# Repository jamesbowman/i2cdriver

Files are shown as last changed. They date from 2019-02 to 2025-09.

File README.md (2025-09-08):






I2CDriver is a tool for controlling any I2C device from your PC's USB port,
and can also monitor and capture I2C traffic.
It connects as a standard USB serial device, so there are no drivers to install.
On the main site
[i2cdriver.com](https://i2cdriver.com),
there are drivers for

* Windows/Mac/Linux GUI
* Windows/Mac/Linux command-line
* Python 2 and 3
* Windows/Mac/Linux C/C++

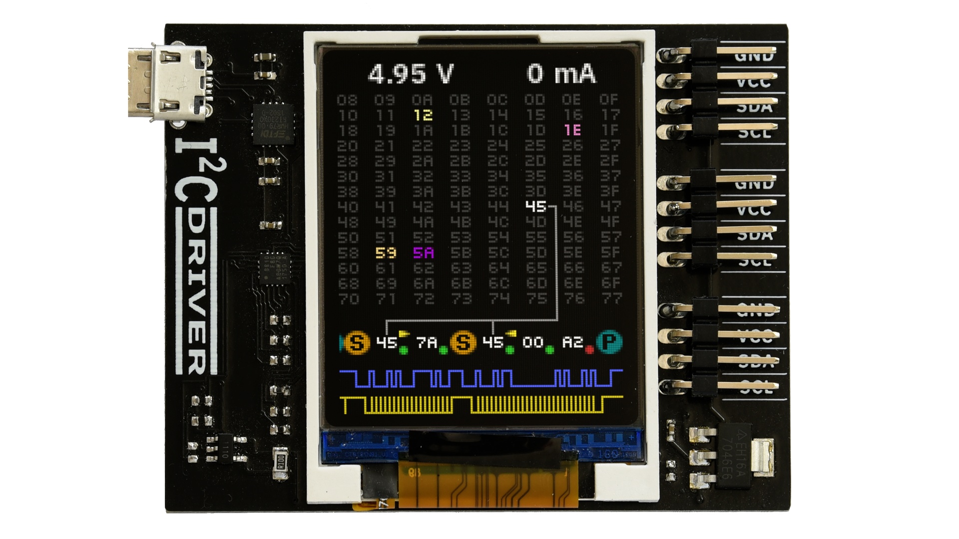
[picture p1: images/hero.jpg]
front


Full documentation is at
[i2cdriver.com](http://i2cdriver.com).

For developers: How to make a release
-------------------------------------

To release Python:

    cd python3
    rm -rf dist/*
    python -m build
    twine check dist/*
    twine upload dist/*

To build the Windows installer, you first need to build the two executables
``i2ccl.exe`` and ``i2cgui.exe`` then use an NSIS script to create the installer.

On Linux cross-compile ``i2ccl``:
  
    cd c
    make -f win32/Makefile

On Windows first make sure that you can run the GUI on the command-line, e.g.

    python python\samples\i2cgui.py

(You may need to install i2cdriver, wxPython and pySerial).

Then build the GUI executable using ``pyinstaller``:

    cd python\samples
    pyinstaller --onefile --windowed --icon=../../images/i2cdriver.ico i2cgui.py

This builds the executable in ``python\samples\dist\i2cgui.exe``.

The Windows installer is built with NSIS (Nullsoft Scriptable Install System). Download and install it.

Copy the two executables ``i2ccl.exe`` and ``i2cgui.exe`` into ``nsis/``.

Then build the installer with NSIS:

    cd nsis
    "C:\Program Files\NSIS\makensis.exe" i2cdriver.nsi

The script ``go.bat`` in ``nsis`` has an example complete flow.

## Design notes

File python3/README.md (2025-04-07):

i2cdriver
=========

I2CDriver is a tool for controlling, monitoring and capturing I2C from your PC's USB port. It connects as a standard USB serial device, so there are no drivers to install."""

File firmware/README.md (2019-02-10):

This is the firmware for the I2CDriver.
It uses the [MyForth](http://www.kiblerelectronics.com/myf/myf.shtml) compiler written by
Charley Shattuck and Bob Nash.

To compile the fonts go into ``assets``
and run ``mkfont.py``. This builds the font sources in ``fonts.fs``

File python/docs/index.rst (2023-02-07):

i2cdriver
=========

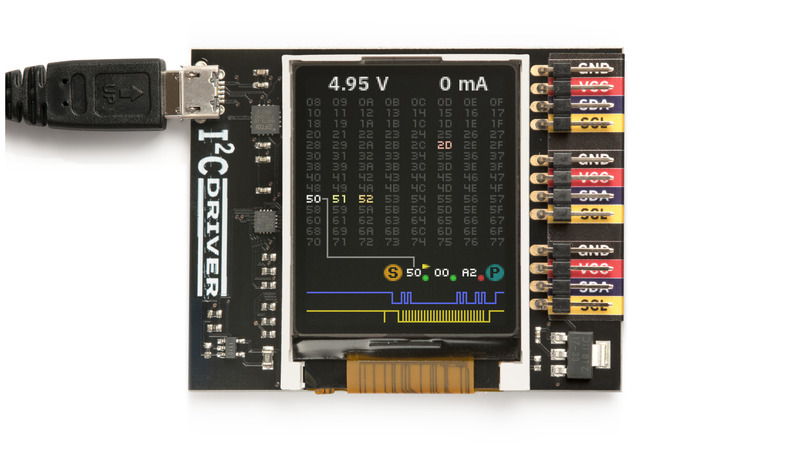
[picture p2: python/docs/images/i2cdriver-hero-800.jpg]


`I²CDriver <https://i2cdriver.com>`_
is an easy-to-use, open source tool for controlling I²C devices over USB.
It works with Windows, Mac, and Linux, and has a built-in color screen
that shows a live "dashboard" of all the I²C activity.

.. toctree::
   :maxdepth: 2
   :caption: Contents:

The I²CDriver User Guide has complete information on the hardware:

https://i2cdriver.com/i2cdriver.pdf

System Requirements
===================

Because it is a pure Python module, ``i2cdriver`` can run on any system supported by ``pyserial``.
This includes:

- Windows 7 or 10
- Mac OS
- Linux, including all Ubuntu distributions

Both Python 2.7 and 3.x are supported.

Installation
------------

The ``i2cdriver`` package can be installed from PyPI using ``pip``::

    $ pip install i2cdriver

Quick start
-----------

To connect to the I2CDriver and scan the bus for connected devices::

    >>> import i2cdriver
    >>> i2c = i2cdriver.I2CDriver("/dev/ttyUSB0")
    >>> i2c.scan()
    -- -- -- -- -- -- -- -- 
    -- -- -- -- -- -- -- -- 
    -- -- -- -- 1C -- -- -- 
    -- -- -- -- -- -- -- -- 
    -- -- -- -- -- -- -- -- 
    -- -- -- -- -- -- -- -- 
    -- -- -- -- -- -- -- -- 
    -- -- -- -- -- -- -- -- 
    48 -- -- -- -- -- -- -- 
    -- -- -- -- -- -- -- -- 
    -- -- -- -- -- -- -- -- 
    -- -- -- -- -- -- -- -- 
    68 -- -- -- -- -- -- -- 
    -- -- -- -- -- -- -- -- 
    [28, 72, 104]

To read the temperature in Celsius from a connected LM75 sensor:

    >>> d=i2cdriver.EDS.Temp(i2c)
    >>> d.read()
    17.875
    >>> d.read()
    18.0

The User Guide at https://i2cdriver.com has more examples.

Module Contents
---------------

.. autoclass:: i2cdriver.I2CDriver
   :member-order: bysource
   :members:
      setspeed,
      setpullups,
      scan,
      reset,
      start,
      read,
      write,
      stop,
      regwr,
      regrd,
      getstatus,
      monitor

.. autoclass:: i2cdriver.START
.. autoclass:: i2cdriver.STOP
.. autoclass:: i2cdriver.BYTE

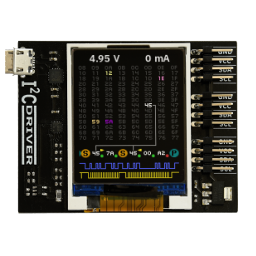
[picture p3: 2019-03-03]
images/i2cdriver.png

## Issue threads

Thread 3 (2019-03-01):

Seems to hang ?

lakidd, 2019-03-01:
Hi I've just received my i2cdriver.
I plug it in and it lights up with the default screen, but it doesn't 'do' anything. When running i2ccl with the correct device name, it just seems to hang, i don't get the status line like your example.
Any hints on troubleshooting ?
Sorry this is on OSX. The python gui also seems to have issues with
```
TypeError: GridSizer(): arguments did not match any overloaded call:
  overload 1: not enough arguments
  overload 2: argument 2 has unexpected type 'int'
  overload 3: not enough arguments
  overload 4: not enough arguments

```
And from my reading, it does need 3x parameters in the call.
Thanks

jamesbowman, 2019-03-01:
What device name are you using? Something like:

``/dev/cu.usbserial-XXXXXXXX``

?

lakidd, 2019-03-01:
Aha its /dev/tty.usbserial-WEATHER...when i change to the cu.usbserial-WEATHER, it comes good, thanks.
What is the difference between those nodes ? I've never understood why both appear and for all other arduino, esp stuff the tty nodes work fine.
Any thoughts on the python issue ?

jamesbowman, 2019-03-01:
Yes it is subtle, but this explains tty vs cu in more detail.

https://pbxbook.com/other/mac-tty.html

Please can you raise a new issue for the Python GUI? (WX changed the parameters of GridSizer between versions.)

jamesbowman, 2019-03-02:
OK, think this is closed.

Closed 2019-03-02.

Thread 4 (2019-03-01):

Python GUI crashes

lakidd, 2019-03-01:
When running the python gui I get

`Traceback (most recent call last):
  File "./i2cgui.py", line 215, in <module>
    f = Frame()
  File "./i2cgui.py", line 99, in __init__
    devgrid = wx.GridSizer(14, 8)
TypeError: GridSizer(): arguments did not match any overloaded call:
  overload 1: not enough arguments
  overload 2: argument 2 has unexpected type 'int'
  overload 3: not enough arguments
  overload 4: not enough arguments`

Has GridSizer in wxPython changed ?

jamesbowman, 2019-03-02:
Confirmed fixed on wx. Closing.

Closed 2019-03-02.

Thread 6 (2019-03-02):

i2cgui is not functional code.

rhyde, 2019-03-02:
I have fixed a couple obvious problems but I quickly realized that this is at best a stub and very little works.  When will a tool that was advertised be available?
Issues: Wrong number of arguments creating the grid layout.
Can't handle non i2c usb-serial devices.

Randomly will not connect claiming bus is busy

jamesbowman, 2019-03-02:
Good points... this in progress.

When it says the bus is busy, what does the ``i2ccl <port> i`` report?

rhyde, 2019-03-02:
The client tool is responding as expected.

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

jamesbowman, 2019-03-02:
Hmm, and ``i2ccl <port> d`` produces a reasonable port scan?

jamesbowman, 2019-03-04:
Think it is feature complete now. Tested on Mac, seems to be usable.
Raised #7 to cover the work to expose the programmable pull-ups.

jamesbowman, 2019-03-04:
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

Closed 2019-03-08.

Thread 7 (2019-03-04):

Feature: Programmable pull-ups

jamesbowman, 2019-03-04:
Need to:
- [ ] document the bit-field
- [ ] expose a proper API
- [ ] add to GUI
- [ ] make a new release

lucasdemarchi, 2019-04-03:
where's the programmable pullup documented? Currently if I read it from python it returns 36. Only place I found a comment was in the code, saying

```
  unsigned int pullups;   // pullup state (6 bits, 1=enabled)
```

Do we have 1 pullup for each SDA/SCL pin? So... are those separate I2C busses? I thought it was a shared bus.

jamesbowman, 2019-04-03:
I've written up how they work here:

https://i2cdriver.com/#pull-up-resistors

next step is to add a control to the GUI.

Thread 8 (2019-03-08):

Where is protocol.md?

njh, 2019-03-08:
Hi,

Just read about this project on an email from Cool Components - looks great!

I just clicked on 'The serial protocol is **very simple**, and there are included drivers for' and got a 404. Where can I find out about the protocol?

Thanks,

nick.

jamesbowman, 2019-03-08:
Fixed the old text, copy-pasted from SPIDriver.
The protocol is covered here

https://i2cdriver.com/#raw-protocol

njh, 2019-03-08:
Ah, great, thanks.

It might be good to add a link to https://i2cdriver.com/ in the header of the Github repo.

jamesbowman, 2019-03-08:
Good idea - done.

Closed 2019-03-08.

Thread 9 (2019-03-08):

I2CDriver Windows release build not working

rlramirez77, 2019-03-08:
1. Need to add a note for users to edit the go.bat with their destination path for i2cdriver-installer.exe output, or have the path resolve for the user automatically
2. Need to mention that Nullsoft Scripting, NSIS is a dependency, user to download and install it
3. Need to reconcile line #63 in i2cdriver.nsi - file "i2ccl.exe" - commenting the line out allows i2cdriver-installer to build, but execution of I2CDriver GUI fails with "Failed to execute script"

jamesbowman, 2019-03-10:
@rlramirez77 when it says "Failed to execute script" what other error text is shown.

rlramirez77, 2019-03-10:
> @rlramirez77 when it says "Failed to execute script" what other error text is shown.

No other message/text, the error is presented in a modal dialog - so it's a typical helpful Windows error message - kek

jamesbowman, 2019-03-10:
OK, to see more error information, do:

    pyinstaller --onefile --icon=../../images/i2cdriver.ico i2cgui.py

(i.e. no ``--windowed`` option). This will leave the console window open and print any error message when the ``.exe`` runs.

rlramirez77, 2019-03-10:
Corresponding output from suggested run (Anaconda is up to date):

(base) C:\Users\Administrator\Downloads\i2cdriver-master\i2cdriver-master\python\samples>pyinstaller --onefile --icon=../../images/i2cdriver.ico i2cgui.py
46 INFO: PyInstaller: 3.4
46 INFO: Python: 3.7.1
46 INFO: Platform: Windows-10-10.0.14393-SP0
46 INFO: wrote C:\Users\Administrator\Downloads\i2cdriver-master\i2cdriver-master\python\samples\i2cgui.spec
46 INFO: UPX is not available.
46 INFO: Extending PYTHONPATH with paths
['C:\\Users\\Administrator\\Downloads\\i2cdriver-master\\i2cdriver-master\\python\\samples',
 'C:\\Users\\Administrator\\Downloads\\i2cdriver-master\\i2cdriver-master\\python\\samples']
62 INFO: checking Analysis
93 INFO: checking PYZ
109 INFO: checking PKG
125 INFO: Bootloader c:\programdata\anaconda3\lib\site-packages\PyInstaller\bootloader\Windows-64bit\run.exe
125 INFO: checking EXE
140 INFO: Building because console changed
140 INFO: Building EXE from EXE-00.toc
249 INFO: SRCPATH [('..\\..\\images\\i2cdriver.ico', None)]
249 INFO: Updating icons from ['..\\..\\images\\i2cdriver.ico'] to C:\Users\ADMINI~1\AppData\Local\Temp\1\tmphuc9ffz2
265 INFO: Writing RT_GROUP_ICON 0 resource with 20 bytes
265 INFO: Writing RT_ICON 1 resource with 75484 bytes
328 INFO: Appending archive to EXE C:\Users\Administrator\Downloads\i2cdriver-master\i2cdriver-master\python\samples\dist\i2cgui.exe
437 INFO: Building EXE from EXE-00.toc completed successfully.

jamesbowman, 2019-03-10:
Looks good... and what does it say when you run ``dist\i2cgui.exe``?

rlramirez77, 2019-03-10:
How do I resolve this dependency?

Traceback (most recent call last):
  File "i2cgui.py", line 11, in <module>
ModuleNotFoundError: No module named 'wx'
[3264] Failed to execute script i2cgui

jamesbowman, 2019-03-10:
It needs wxPython, installation instructions are here

https://www.wxpython.org/pages/downloads/

if you are on Anaconda then it is here:

https://anaconda.org/anaconda/wxpython

rlramirez77, 2019-03-10:
Installed via Anaconda - same line 11 error.

jamesbowman, 2019-03-10:
OK, if you run it from the command-line with:

    python i2cgui.py

then do you see the same message about ``No module named 'wx'``?

rlramirez77, 2019-03-10:
Getting closer to the error:

(base) C:\Users\Administrator\Downloads\i2cdriver-master\i2cdriver-master\python\samples>python i2cgui.py
Traceback (most recent call last):
  File "i2cgui.py", line 14, in <module>
    from i2cdriver import I2CDriver
  File "C:\ProgramData\Anaconda3\lib\site-packages\i2cdriver.py", line 13, in <module>
    import bargraph
  File "C:\Users\Administrator\Downloads\i2cdriver-master\i2cdriver-master\python\samples\bargraph.py", line 10, in <module>
    from i2cdriver import I2CDriver
ImportError: cannot import name 'I2CDriver' from 'i2cdriver' (C:\ProgramData\Anaconda3\lib\site-packages\i2cdriver.py)

jamesbowman, 2019-03-10:
Aha. please update i2cdriver:

    pip install -U i2cdriver

rlramirez77, 2019-03-10:
Better, but 2 things. How do I specify COM9 as an argument to the executable? Like SPIDriver does, I would not throw an error if the i2cdriver hardware is unplugged when the GUI is run.

(base) C:\Users\Administrator\Downloads\i2cdriver-master\i2cdriver-master\python\samples\dist>i2cgui.exe
Traceback (most recent call last):
  File "i2cgui.py", line 334, in <module>
  File "i2cgui.py", line 209, in __init__
  File "i2cgui.py", line 266, in connect
  File "site-packages\i2cdriver.py", line 47, in __init__
  File "site-packages\serial\serialwin32.py", line 31, in __init__
  File "site-packages\serial\serialutil.py", line 240, in __init__
  File "site-packages\serial\serialwin32.py", line 62, in open
serial.serialutil.SerialException: could not open port 'COM1': PermissionError(13, 'Access is denied.', None, 5)
[7200] Failed to execute script i2cgui

bruceephx, 2019-03-17:
I just received my I2CDriver kit and following the getting-started page I downloaded the Windows Installer program and ran it as Administrator.  It seemed to install the i2cgui.exe and the i2ccl.exe without issue.  I ran the i2cgui.exe as Adminsitrator and I keep getting the "Failed to execute script i2cgui" response.  I'm running Windows 10 Pro x64 latest release.

I just tried the command line "i2ccl.exe" COM2 i" and that gave the response from the I2CDriver board with stats.  So the board appears to be running and communicating.

Ideas or thoughts?

jamesbowman, 2019-03-17:
Hi @bruceephx - What is the output of the "mode" command? Are there other COM ports? That might be a clue as to why i2cgui is failing.

jamesbowman, 2019-03-18:
@rlramirez77 and @bruceephx  I have built the new version of i2cgui at:

https://excamera.com/files/i2cgui.exe

This version is a bit more robust about handling ports, accepts a port on the command-line, and displays a dialog if it catches a fault. Please let me know how it works. Thanks.

rlramirez77, 2019-03-24:
That has it working now, thanks.

jamesbowman, 2019-03-26:
Great, thanks. Closing.

Closed 2019-03-26.

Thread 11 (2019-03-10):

Unable to see Stop button in 1366 x 768 screen resolution

gojimmypi, 2019-03-10:
perhaps the radio buttons can be vertically pushed closer together a bit, or add a scrollbar for those that have lower resolution screens? I would have submitted PR for this, but could not find the GUI version source code.

jamesbowman, 2019-03-10:
Aha, this is on Windows.
Sure, there are a couple of changes I can make.
btw the source is at ``python/samples/i2cgui.py``

jamesbowman, 2019-03-10:
Yes, pushing the radio buttons closer together looks good. Now fits in 768:

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

gojimmypi, 2019-03-10:
yes, that works perfectly! (and looks better, too -  in addition to being able to see the Stop button)

thank you for the prompt response & I didn't realize Windows GUI was python based.

Closed 2019-03-10.

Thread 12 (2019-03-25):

Windows app buttons disabled at startup

gojimmypi, 2019-03-25:
I'm test driving an INA219 I2C current sensor. The I2CDriver board sees the device at address x40, but the `read` and `write` buttons are initially disabled.

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

If I plug in a second device, Ic2 address = x60, select that one and then go back and select the 0x40 device, the buttons are then enabled.

jamesbowman, 2019-03-26:
This seems to be a difference in radio button behavior between our versions of Windows. Surprising!

If you start with 0x40 attached, then click on the 0x40 radio button, do "read" and "write" light up?

When I start it with a single device (74 in my case) the device map doesn't light up, I have to click it. Then the RADIOBUTTON event happens and the GUI enables the buttons:

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

I'm running Windows 10.

gojimmypi, 2019-03-28:
Well, I found a sequence of events to reproduce this. The last time it seemed that the problem continually occurred.

With the I2CDriver powered off, plug in a device. (I plugged mine into the connector closest to the top of the display).  Launch the software. No items are selected and the buttons are grayed out. Click the ID of your selected item (in my case 40). The `Read` and `Write` buttons become active.

While leaving the I2CDriver board powered up, unplug the single I2C test device. The `Read` and `Write` buttons become inactive and grayed out. The selected device radio button remains selected, but also grayed out.

Re-plug the I2C device. The software recognizes that a device has been plugged in, the radio button selection is no longer grayed out - however clicking on it does not enable the buttons, perhaps because the radio button was already selected? Having only one device - there's no way to un-select and re-select it.

It seems that perhaps the  `Read` and `Write`  buttons are enabled only upon a state change from the radio button not selected to selected.

I'm also running Windows:
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

jamesbowman, 2019-03-29:
Aha, that's very clear, thanks.

I committed a fix, and built a test binary here:

https://excamera.com/files/i2cgui.exe

jamesbowman, 2020-01-08:
Fixed, closing.

Closed 2020-01-08.

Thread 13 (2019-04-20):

Capture Mode

brotherdust, 2019-04-20:
Hi!
THANK YOU for making this device! It's so useful!

While looking through the [documentation](https://i2cdriver.com/), I noticed there's a stub header for "Capture Mode", but nothing below it. Are there any plans for a capture mode to be supported? If so, when? I'd like to contribute to your project where I can, so I'd be happy to write up the documentation for this feature once it's available.

Thanks!

simon-rob, 2019-04-29:
+1
I twas hoping capture mode would allow capturing of I2C frames as monitor mode seems only to so the current frame on the display which is limited in use when debugging. (due to the small screen)

jamesbowman, 2019-04-29:
Hi all, yes, really sorry this isn't. It's coming today.

simon-rob, 2019-04-29:
Great, looking forward to giving it ago.

jamesbowman, 2019-04-30:
Capture to file is implemented in the new release 0.0.5.

https://i2cdriver.com/windows

It's documented on p.18 of the user guide:

https://i2cdriver.com/i2cdriver.pdf

Note that there's no live graphical display at the yet, but the command-line version does print all the traffic as it arrives.

simon-rob, 2019-04-30:
James,

I am using Python 2.7  and I get the follow error when trying to capture:
  File "/usr/lib/python2.7/threading.py", line 801, in __bootstrap_inner
    self.run()
  File "/usr/lib/python2.7/threading.py", line 754, in run
    self.__target(*self.__args, **self.__kwargs)
  File "i2cgui.py", line 48, in capture_thr
    c = sd.capture_start(True)
TypeError: capture_start() takes exactly 1 argument (2 given)

If I remove from capture_start() I then get:
  File "/usr/lib/python2.7/threading.py", line 801, in __bootstrap_inner
    self.run()
  File "/usr/lib/python2.7/threading.py", line 754, in run
    self.__target(*self.__args, **self.__kwargs)
  File "i2cgui.py", line 52, in capture_thr
    for token in c():
  File "build/bdist.linux-x86_64/egg/i2cdriver.py", line 261, in parser
    for n in nstream():
  File "build/bdist.linux-x86_64/egg/i2cdriver.py", line 258, in nstream
    yield (b >> 4) & 0xf
TypeError: unsupported operand type(s) for >>: 'str' and 'int'

I see that i2cdriver.py has support for PYTHON2, but i guess some of the new capture code needs adapting! (I did have a go, but it kept giving the same error on 258 to my surprise)

Simon

jamesbowman, 2019-05-02:
@simon-rob I think you might be running the latest gui with an old i2cdriver. Did you do

  pip install -U i2cdriver

(or similar) before running the GUI?

simon-rob, 2019-05-02:
James,

I have run python2 setup.py install
I also tried pip install -U i2driver

but I still get:

  File "/usr/lib/python2.7/threading.py", line 801, in __bootstrap_inner
    self.run()
  File "/usr/lib/python2.7/threading.py", line 754, in run
    self.__target(*self.__args, **self.__kwargs)
  File "i2cgui.py", line 47, in capture_thr
    c = sd.capture_start(True)
TypeError: capture_start() takes exactly 1 argument (2 given)

jamesbowman, 2019-05-02:
That definitely looks like a version mismatch because capture_start's signature changed in 0.0.5.

If I do:

```
$ python2
Python 2.7.6 (default, Oct 26 2016, 20:30:19)
[GCC 4.8.4] on linux2
Type "help", "copyright", "credits" or "license" for more information.
>>> import i2cdriver
>>> i2cdriver.__version__
'0.0.5'
```

do you get the same version 0.0.5?

simon-rob, 2019-05-02:
James,

No, I get version 0.0.4.

I have uninstalled the i2cdriver using  pip uninstall i2driver and then reinstalled it again..

Now no error and the correct version 0.0.5.

Thanks for you help,

Simon

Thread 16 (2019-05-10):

I2CDRIVER.C won't compile with MSVC

TheSlat, 2019-05-10:
The following code fails to compile in Visual Studio 2019 with the error:
```
Severity	Code	Description	File	Line	Suppression State
Error	C2133	'mm': unknown size	..\i2cdriver.c	42
Error	C2057	expected constant expression	..\i2cdriver.c	42
Error	C2466	cannot allocate an array of constant size 0	..\i2cdriver.c	42

```

https://github.com/jamesbowman/i2cdriver/blob/2697bf5046094cddbebcbdee89a480c77b5c3f22/c/common/i2cdriver.c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

my quick fix:
```
    char mm[256];
    sprintf(mm, "%s failed with error %lu:\n%s", func_name, dw, (char*)lpMsgBuf);
```
unsure if there is a better way, just wanted to open the issue.

Also, I would suggest placing `#define NOMINMAX` before including windows.h to prevent windows from defining the min and max macros and clashing with other code.

TheSlat, 2019-05-11:
Also noticed that I had moved `#include <unistd.h>` to the `#if !defined(WIN32)` section since MSVC doesn't have that header and mingw doesn't need it. Also a `==` where i think there should be a `=` on line 58.

If you want I can fork and open a pull request to group these things together, I am using both the I2C driver and SPI driver pretty heavily in MSVC at work.

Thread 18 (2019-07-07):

Can't connect in Linux/Ubuntu

kylemallory, 2019-07-07:
I recently purchased this, and was really excited about using it for some of my embedded development. It took a bit to get wxPython installed property on Ubuntu (needed a bunch of additional packages that were in your instructions), but eventually I got it sorted.

Now that it's installed, I can run i2cgui.py, but I can't select a serial port from the drop down. I can see the /dev/ttyUSB0 being created when I connect it, and my user has 'dialout' permissions, but the GUI is almost entirely grayed out, and there is no output on the console.

I'd love to see this work. Any ideas for what might be causing the problems, or steps for further troubleshooting?

Thanks!

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

jamesbowman, 2019-07-07:
First question, when you attach the I2CDriver, does the I2CDriver's screen light up, and does it appear as a new device, like ``/dev/ttyUSB0``?

kylemallory, 2019-07-07:
Yes, it powers on, the display shows, and the OS detects the USB device, and registers as /dev/ttyUSB0. I have added my user to the "dialout" group, so permissions appear not to be a problem either.  Is there a 'debug' or 'logging' argument for the i2cgui.py that I can try?

jamesbowman, 2019-07-07:
OK, that narrows it down.

- [ ] Can I confirm that you logged out and back in, so the dialout group change took effect?
- [ ] The command-line tool might show the problem, if you build it and do ``i2ccl /dev/ttyUSB0 i`` what does it show?

kylemallory, 2019-07-07:
I also just noticed; when I start `i2cgui.py` the LCD backlight will brighten for about 2 seconds, and then dim back to normal.  If I close the app, and reopen, the same "bright/dim" change repeats each time I restart it.

kylemallory, 2019-07-07:
I can completely rebooted after adding myself to the group.  I'll try the `i2ccl` tool...

kylemallory, 2019-07-07:
Cloned, built, and ran...
```
$ ./i2ccl /dev/ttyUSB0 i
uptime 19945  5.388 V  0 mA  23.0 C SDA=0 SCL=1 speed=100 kHz
```
However:
```
$ ./i2ccl /dev/ttyUSB0 d
```
seems to hang indefinitely (I can abort/Ctrl+C).  Calling `i2ccl /dev/ttyUSB0 i` a second time also hung.  I had a i2c LCD display connected.  I remove that, and powered off the i2cdriver, and repowered.  At this point, both queries returned successfully.

I tried a different OLED display, and the device is working correctly, including in i2cgui.py.

There must have been something about the other LCD display that was messing up i2cdriver.  I think we can close this ticket, unless you'd like to do any additional troubleshooting to try and figure out what it going on.

Closed 2020-01-08.

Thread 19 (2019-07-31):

Issue with GUI on MacOS 10.14.6

joshrawls, 2019-07-31:
I have the device working, occasionally. When it doesn't work I get a few errors in terminal.

I'm still learning programming in general and new to Python, so any help would be appreciated. Thanks!

The first error only appears once:

`Traceback (most recent call last):
  File "/usr/local/bin/i2cgui.py", line 342, in refresh
    devs = self.sd.scan(True)
  File "/Library/Python/2.7/site-packages/i2cdriver.py", line 180, in scan
    d = struct.unpack("112c", self.ser.read(112))
struct.error: unpack requires a string argument of length 112
`

The second error loops until I terminate it:
`Traceback (most recent call last):
  File "/usr/local/bin/i2cgui.py", line 323, in refresh
    self.sd.getstatus()
  File "/Library/Python/2.7/site-packages/i2cdriver.py", line 449, in getstatus
    ccitt_crc) = body.split()
ValueError: need more than 0 values to unpack`

g5pw, 2021-04-10:
Uh, I'm seeing the same error on macOS Big Sur 11.2.3. Did you manage to solve it in any way?

jamesbowman, 2021-04-10:
@g5pw does this error happen intermittently, or every time?

g5pw, 2021-04-11:
Looks like it happens every time, and the GUI locks up :/

joshrawls, 2021-04-23:
I never found a fix, so I stopped using the product and got a good oscilloscope that has decoding.

g5pw, 2021-04-26:
Hey, I think the issue still exists, regardless of @joshrawls' usage of the product. I got one, and it looks nice, and I'd like to use it if possible 😅 I'll try to test the UI part, but from a quick glance it looks like a firmware hang, i.e. the device is not sending any more data.

Closed 2021-04-23.

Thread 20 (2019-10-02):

bitbang?

williamkapke, 2019-10-02:
While creating a [Node.js module](https://www.npmjs.com/package/i2cdriver) for this device- I came across bitbang mode (commands `b` & `i`)... but [I couldn't find any further details on it](https://github.com/jamesbowman/i2cdriver/search?q=bitbang&unscoped_q=bitbang).

Can you share insights on how this works? Maybe it's still in development?

jamesbowman, 2019-11-14:
Pushed new PDF to public site.
Closing.

Closed 2019-11-14.

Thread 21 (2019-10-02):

Monitor mode

williamkapke, 2019-10-02:
My understanding is that monitor mode allows us to monitor an i2c bus- which seems pretty cool.

I'm curious about wiring and voltages... and if I'm way off base on what I'm understanding so far. I thought I better ask a few questions before I start plugging things in!

For what I've used my board for so far- my computer has been the master and has been providing power to the attached devices.

Monitor mode sounds like there is and existing bus that we get to plug in to and listen in. That would mean another device is the master and power is coming from elsewhere. If true- does the i2cdriver draw power from the bus then? Can/should usb be connected without issue?

When connected to USB, i2cdriver produces 3.3v on the VDD pins. What if the bus to be monitored is using VDD=5v?

jamesbowman, 2019-10-04:
Hi William,

Good questions. I'm going to improve the coverage of this topic in the manual,

I2CDriver is always USB-powered, so never draws power from the target circuit.
For monitoring an existing circuit, it needs GND, SCL and SDA to be connected to it.
You can optionally connect VCC to the circuit if you want I2CDriver to power it.
In the case you mention of a VDD=5V circuit, the only connections are GND, SCL and SDA. The inputs to I2CDriver are 5V-safe, so electrically this is fine.

Hope this helps - I'm leaving this ticket open until the proper section in the user guide is written.

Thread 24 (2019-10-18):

GUI should recognise I2CMini, disable current/voltage readouts

jamesbowman, 2019-10-18:
When device is I2CMini, which has no current or voltage sensing, those readouts should be disabled.

williamkapke, 2019-10-18:
🤔 How will the I2CMini be identified?

I'm guessing the 'identifier' of the `status response` (`?` command) will say 'I2CMini'?

Since this is a fixed length string- also I guessing it'll be padded at the end with some whitespace.

jamesbowman, 2019-10-18:
Yes, for I2CDriver the status response field **identifier** field is ``i2cdriver1``:

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

but for I2CMini has ``i2cdriverm``.

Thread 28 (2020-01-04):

regrd with more than 255 bytes

jamesbowman, 2020-01-04:
It is not currently possible to do a regrd() to receive more than 255 bytes.

The regrd() implementation should handle this by expanding the request to:
```
self.start(dev, 0)
self.write([reg])
self.start(dev, 1)
r = self.read(256)
self.stop()
```

jamesbowman, 2020-01-08:
Fixed, closing.

Closed 2020-01-08.

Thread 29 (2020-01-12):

Add path to i2ccl.exe on Windows

jamesbowman, 2020-01-12:
Add the i2ccl.exe path to PATH in the Windows installer.

jamesbowman, 2020-01-26:
Tested install and uninstall on Win10, seems to be working. Closing.

Closed 2020-01-26.

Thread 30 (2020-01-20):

i2cdriver hardware hangs up

codehero, 2020-01-20:
There should be no issue at all receiving echo responses. i2cdriver fails to respond.
I am not a MyForth expert nor will I ever be, but I don't see that the watchdog timer is used. I don't see any exception vectors handled either. This looks like it could be a 5 star product but it needs the basics covered!

openat(AT_FDCWD, "/dev/ttyUSB0", O_RDWR|O_NOCTTY) = 3
ioctl(3, TCGETS, {B1000000 -opost -isig -icanon -echo ...}) = 0
ioctl(3, TCGETS, {B1000000 -opost -isig -icanon -echo ...}) = 0
ioctl(3, SNDCTL_TMR_START or TCSETS, {B1000000 -opost -isig -icanon -echo ...}) = 0
ioctl(3, TCGETS, {B1000000 -opost -isig -icanon -echo ...}) = 0
write(3, "@@@@@@@@@@@@@@@@@@@@@@@@@@@@@@@@"..., 64) = 64
write(3, "eA", 2)                       = 2
read(3,

jamesbowman, 2020-01-20:
Right, I see this:

```
$ strace ./build/i2ccl /dev/ttyUSB3 i
...
openat(AT_FDCWD, "/dev/ttyUSB3", O_RDWR|O_NOCTTY) = 4
ioctl(4, TCGETS, {B1000000 -opost -isig -icanon -echo ...}) = 0
ioctl(4, TCGETS, {B1000000 -opost -isig -icanon -echo ...}) = 0
ioctl(4, SNDCTL_TMR_START or TCSETS, {B1000000 -opost -isig -icanon -echo ...}) = 0
ioctl(4, TCGETS, {B1000000 -opost -isig -icanon -echo ...}) = 0
write(4, "@@@@@@@@@@@@@@@@@@@@@@@@@@@@@@@@"..., 64) = 64
write(4, "eA", 2)                       = 2
read(4, "A", 1)                         = 1
```

This might just be a bad unit. So please can you confirm the basics:

- has it ever connected, or has it got into some hung state before this?
- that port `/dev/ttyUSB0` is your I2CDriver, and not some other device
- that nothing is plugged into the I2CDriver's I2C ports, at least to begin with

The firmware does catch failures, using the SiLabs EFM8 system of timers and interrupts.

codehero, 2020-01-20:
I have only tested with an I2C slave microcontroller. I have connected to this microcontroller before with Linux GPIO I2C.

I am 100% sure /dev/ttyUSB0 is the I2CDriver FT230X device

I am not sure what you mean by "that nothing is plugged into the I2CDriver's I2C ports, at least to begin with"? Do you mean on power up, on i2c_connect()? Please provide specific context.

You say the FW catches failures, but if it does they are not reported to the user via serial. For example if there is a watchdog failure, a brownout condition or some other exceptional HW condition this should be reported via serial. There is no bootup message sent out over UART when the unit starts. There is no pulse from the unit. There isn't even a blinking light on the OLED display.

jamesbowman, 2020-01-20:
At startup, the display should look like this:

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

To clarify, by "nothing plugged in" I mean no I2C peripherals are connected. So the full procedure:

1. Take I2CDriver, with no I2C peripherals connected
2. connect USB cable
3. confirm that the I2CDriver display lights up, as shown above
4. confirm the USB port as /dev/ttyUSBx
5. Use "i2ccl /dev/ttyUSBx i" to confirm that the I2CDriver is alive

Or have you already reached this point?

codehero, 2020-01-20:
This point has worked for me before. I have tried a few more times and got this

openat(AT_FDCWD, "/dev/ttyUSB0", O_RDWR|O_NOCTTY) = 3
ioctl(3, TCGETS, {B1000000 -opost -isig -icanon -echo ...}) = 0
ioctl(3, TCGETS, {B1000000 -opost -isig -icanon -echo ...}) = 0
ioctl(3, SNDCTL_TMR_START or TCSETS, {B1000000 -opost -isig -icanon -echo ...}) = 0
ioctl(3, TCGETS, {B1000000 -opost -isig -icanon -echo ...}) = 0
write(3, "@@@@@@@@@@@@@@@@@@@@@@@@@@@@@@@@"..., 64) = 64
write(3, "eA", 2)                       = 2
read(3, "A", 1)                         = 1
write(3, "e\r", 2)                      = 2
read(3, "\r", 1)                        = 1
write(3, "e\n", 2)                      = 2
read(3, "\n", 1)                        = 1
write(3, "e\0", 2)                      = 2
read(3, "\0", 1)                        = 1
write(3, "?", 1)                        = 1
read(3, "[i2cdriver1 DO01JT5U 000000239 4"..., 80) = 80
write(3, 0x78, 1)                       = -1 EFAULT (Bad address)
write(3, 0x72, 1)                       = -1 EFAULT (Bad address)
write(3, 0x31, 1)                       = -1 EFAULT (Bad address)
write(3, 0x69, 1)                       = -1 EFAULT (Bad address)
write(3, "sb", 2)                       = 2
read(3,

codehero, 2020-01-20:
openat(AT_FDCWD, "/lib/x86_64-linux-gnu/libc.so.6", O_RDONLY|O_CLOEXEC) = 3
read(3, "\177ELF\2\1\1\3\0\0\0\0\0\0\0\0\3\0>\0\1\0\0\0\260A\2\0\0\0\0\0"..., 832) = 832
fstat(3, {st_mode=S_IFREG|0755, st_size=1996592, ...}) = 0
mmap(NULL, 8192, PROT_READ|PROT_WRITE, MAP_PRIVATE|MAP_ANONYMOUS, -1, 0) = 0x7fb7fde41000
mmap(NULL, 2004992, PROT_READ, MAP_PRIVATE|MAP_DENYWRITE, 3, 0) = 0x7fb7fdc57000
mprotect(0x7fb7fdc79000, 1826816, PROT_NONE) = 0
mmap(0x7fb7fdc79000, 1511424, PROT_READ|PROT_EXEC, MAP_PRIVATE|MAP_FIXED|MAP_DENYWRITE, 3, 0x22000) = 0x7fb7fdc79000
mmap(0x7fb7fddea000, 311296, PROT_READ, MAP_PRIVATE|MAP_FIXED|MAP_DENYWRITE, 3, 0x193000) = 0x7fb7fddea000
mmap(0x7fb7fde37000, 24576, PROT_READ|PROT_WRITE, MAP_PRIVATE|MAP_FIXED|MAP_DENYWRITE, 3, 0x1df000) = 0x7fb7fde37000
mmap(0x7fb7fde3d000, 14336, PROT_READ|PROT_WRITE, MAP_PRIVATE|MAP_FIXED|MAP_ANONYMOUS, -1, 0) = 0x7fb7fde3d000
close(3)                                = 0
arch_prctl(ARCH_SET_FS, 0x7fb7fde42540) = 0
mprotect(0x7fb7fde37000, 16384, PROT_READ) = 0
mprotect(0x559d19931000, 4096, PROT_READ) = 0
mprotect(0x7fb7fde80000, 4096, PROT_READ) = 0
munmap(0x7fb7fde43000, 78628)           = 0
openat(AT_FDCWD, "/dev/ttyUSB0", O_RDWR|O_NOCTTY) = 3
ioctl(3, TCGETS, {B1000000 -opost -isig -icanon -echo ...}) = 0
ioctl(3, TCGETS, {B1000000 -opost -isig -icanon -echo ...}) = 0
ioctl(3, SNDCTL_TMR_START or TCSETS, {B1000000 -opost -isig -icanon -echo ...}) = 0
ioctl(3, TCGETS, {B1000000 -opost -isig -icanon -echo ...}) = 0
write(3, "@@@@@@@@@@@@@@@@@@@@@@@@@@@@@@@@"..., 64) = 64
write(3, "eA", 2)                       = 2
read(3,

codehero, 2020-01-20:
So sometimes I get a hangup and sometimes I don't. When it does hangup I have to power cycle and the Voltage reading never changes.

jamesbowman, 2020-01-20:
OK, I think what you are saying is that the I2CDriver display and communications are working, and that after some communication with a microcontroller I2C Slave, the I2CDriver can hang.

Can you provide any more details on the I2C transaction that leads to the hang?

codehero, 2020-01-20:
New information here!

Three program invocations.
The first shows code with no bugs. This runs fine.
The second has the following bugs: Single character strings are mistyped as single characters ("a" vs 'a'). This shows an address error in strace
The third invocation the code is run without the bug and exhibits the no response behaviour.

This is quite possible a bug in the Linux ftdi driver. Or it is a bug in your FW. I don't know which. I think I have given you enough to reproduce it. Please ask more questions if needed.

TRACES

This runs fine

`openat(AT_FDCWD, "/dev/ttyUSB0", O_RDWR|O_NOCTTY) = 3
ioctl(3, TCGETS, {B9600 opost isig icanon echo ...}) = 0
ioctl(3, TCGETS, {B9600 opost isig icanon echo ...}) = 0
ioctl(3, SNDCTL_TMR_START or TCSETS, {B1000000 -opost -isig -icanon -echo ...}) = 0
ioctl(3, TCGETS, {B1000000 -opost -isig -icanon -echo ...}) = 0
write(3, "@@@@@@@@@@@@@@@@@@@@@@@@@@@@@@@@"..., 64) = 64
write(3, "eA", 2)                       = 2
read(3, "A", 1)                         = 1
write(3, "e\r", 2)                      = 2
read(3, "\r", 1)                        = 1
write(3, "e\n", 2)                      = 2
read(3, "\n", 1)                        = 1
write(3, "e\0", 2)                      = 2
read(3, "\0", 1)                        = 1
write(3, "?", 1)                        = 1
read(3, "[i2cdriver1 DO01JT5U 000000013 4"..., 80) = 80
close(3)                                = 0
openat(AT_FDCWD, "/dev/ttyUSB0", O_RDWR|O_NOCTTY) = 3
ioctl(3, TCGETS, {B1000000 -opost -isig -icanon -echo ...}) = 0
ioctl(3, TCGETS, {B1000000 -opost -isig -icanon -echo ...}) = 0
ioctl(3, SNDCTL_TMR_START or TCSETS, {B1000000 -opost -isig -icanon -echo ...}) = 0
ioctl(3, TCGETS, {B1000000 -opost -isig -icanon -echo ...}) = 0
write(3, "@@@@@@@@@@@@@@@@@@@@@@@@@@@@@@@@"..., 64) = 64
write(3, "eA", 2)                       = 2
read(3, "A", 1)                         = 1
write(3, "e\r", 2)                      = 2
read(3, "\r", 1)                        = 1
write(3, "e\n", 2)                      = 2
read(3, "\n", 1)                        = 1
write(3, "e\0", 2)                      = 2
read(3, "\0", 1)                        = 1
write(3, "?", 1)                        = 1
read(3, "[i2cdriver1 DO01JT5U 000000013 4"..., 80) = 80
write(3, "x", 1)                        = 1
write(3, "r", 1)                        = 1
write(3, "1", 1)                        = 1
write(3, "i", 1)                        = 1
write(3, "sb", 2)                       = 2
read(3, "3", 1)                         = 1
write(3, "\300\1", 2)                   = 2
read(3, "\0", 1)                        = 1
write(3, "p", 1)                        = 1
exit_group(0)                           = ?`

This does not
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
codehero, 2020-01-20:
I should note that I am running on an osboxes ubuntu VM

Linux osboxes 4.18.0-25-generic #26-Ubuntu SMP Mon Jun 24 09:32:08 UTC 2019 x86_64 x86_64 x86_64 GNU/Linux

jamesbowman, 2020-01-20:
Aha, thanks. What is running this on the Linux box? I assume it is C code that you have for driving the I2CDriver, but want to confirm.

codehero, 2020-01-21:
This is all C code. Not sure I understand why I would need 2 separate reads after 'a N' (read N bytes with ack). It seems I need 1 call for the status and 1 for the data. Why is this so?

jamesbowman, 2020-01-21:
Looking at the trace... first observation is that the 'x' (bus reset) command sends a response bye back, with the state of SDA,ACL lines in the two low bits.
Am updating the C sample code to include reset now.

codehero, 2020-01-21:
Thanks for patching, but can you please just fix up the documentation with precise definitions of what commands are accepted and precisely what responses are sent back.

First off page 24 talks about toggling a CS??? line with commands not even in the table.
Apparently '_' is a command in the code and it's not in the DOCS???

Please go back and fix the documentation so someone skilled in the art can write a proper C API for it. The only reason I haven't tossed this product in the junk bin is because I think it is fundamentally good and just needs some rigorous attention.

jamesbowman, 2020-01-21:
Agreed, on it.

jamesbowman, 2020-01-22:
Updated doc, section 7.4 has all the core commands:

https://i2cdriver.com/i2cdriver.pdf

Capture mode is TBD.

jamesbowman, 2020-01-23:
Did you get a chance to look at the updated docs? They should have enough detail to write an API.

Reading through the C reference code, I notice that it is incorrect for long (>64 byte) reads, and have raised #34 for the fix.

codehero, 2020-01-23:
Yes I have and it makes more sense now. I am going forward with my own C code from scratch given your docs. I am looking forward to monitor mode!

jamesbowman, 2020-02-19:
OK to close this one?

Closed 2020-02-19.

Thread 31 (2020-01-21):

How many status bytes are supposed to read after a command???

codehero, 2020-01-21:
It seems that after doing a [0xc0 0x01] command to I2C driver, I sometimes have to read 2 status bytes before the next command processes. The following are 2 straces. The first command sometimes results in a hangup; the second always seems to not hang but seomtimes ends up with weird communication errors. The difference is in the second is that a read for 16 bytes commences after the write request

openat(AT_FDCWD, "\x2f\x64\x65\x76\x2f\x74\x74\x79\x55\x53\x42\x30", O_RDWR|O_NOCTTY) = 3
ioctl(3, TCGETS, {B1000000 -opost -isig -icanon -echo ...}) = 0
ioctl(3, TCGETS, {B1000000 -opost -isig -icanon -echo ...}) = 0
ioctl(3, SNDCTL_TMR_START or TCSETS, {B1000000 -opost -isig -icanon -echo ...}) = 0
ioctl(3, TCGETS, {B1000000 -opost -isig -icanon -echo ...}) = 0
write(3, "\x40\x40\x40\x40\x40\x40\x40\x40\x40\x40\x40\x40\x40\x40\x40\x40\x40\x40\x40\x40\x40\x40\x40\x40\x40\x40\x40\x40\x40\x40\x40\x40"..., 64) = 64
write(3, "\x65\x41", 2)                 = 2
read(3, "\x41", 1)                      = 1
write(3, "\x65\x0d", 2)                 = 2
read(3, "\x0d", 1)                      = 1
write(3, "\x65\x0a", 2)                 = 2
read(3, "\x0a", 1)                      = 1
write(3, "\x65\x00", 2)                 = 2
read(3, "\x00", 1)                      = 1
write(3, "\x3f", 1)                     = 1
read(3, "\x5b\x69\x32\x63\x64\x72\x69\x76\x65\x72\x31\x20\x44\x4f\x30\x31\x4a\x54\x35\x55\x20\x30\x30\x30\x30\x30\x30\x38\x30\x38\x20\x34"..., 80) = 80
write(3, "\x78", 1)                     = 1
write(3, "\x72", 1)                     = 1
write(3, "\x31", 1)                     = 1
write(3, "\x69", 1)                     = 1
write(3, "\x73\x62", 2)                 = 2
read(3, "\x33", 1)                      = 1

write(3, "\xc0\x01", 2)                 = 2
read(3, "\x31", 1)                      = 1
write(3, "\x70", 1)                     = 1

openat(AT_FDCWD, "\x2f\x64\x65\x76\x2f\x74\x74\x79\x55\x53\x42\x30", O_RDWR|O_NOCTTY) = 3
ioctl(3, TCGETS, {B1000000 -opost -isig -icanon -echo ...}) = 0
ioctl(3, TCGETS, {B1000000 -opost -isig -icanon -echo ...}) = 0
ioctl(3, SNDCTL_TMR_START or TCSETS, {B1000000 -opost -isig -icanon -echo ...}) = 0
ioctl(3, TCGETS, {B1000000 -opost -isig -icanon -echo ...}) = 0
write(3, "\x40\x40\x40\x40\x40\x40\x40\x40\x40\x40\x40\x40\x40\x40\x40\x40\x40\x40\x40\x40\x40\x40\x40\x40\x40\x40\x40\x40\x40\x40\x40\x40"..., 64) = 64
write(3, "\x65\x41", 2)                 = 2
read(3, "\x41", 1)                      = 1
write(3, "\x65\x0d", 2)                 = 2
read(3, "\x0d", 1)                      = 1
write(3, "\x65\x0a", 2)                 = 2
read(3, "\x0a", 1)                      = 1
write(3, "\x65\x00", 2)                 = 2
read(3, "\x00", 1)                      = 1
write(3, "\x3f", 1)                     = 1
read(3, "\x5b\x69\x32\x63\x64\x72\x69\x76\x65\x72\x31\x20\x44\x4f\x30\x31\x4a\x54\x35\x55\x20\x30\x30\x30\x30\x30\x34\x32\x37\x35\x20\x34"..., 80) = 80
write(2, "\x5b\x69\x32\x63\x64\x72\x69\x76\x65\x72\x31\x20\x44\x4f\x30\x31\x4a\x54\x35\x55\x20\x30\x30\x30\x30\x30\x34\x32\x37\x35\x20\x34"..., 81[i2cdriver1 DO01JT5U 000004275 4.981 000 27.4 I 1 1 100 24 0168                ]
) = 81
write(3, "\x78", 1)                     = 1
write(3, "\x72", 1)                     = 1
write(3, "\x31", 1)                     = 1
write(3, "\x69", 1)                     = 1         = 4
write(3, "\x73\x62", 2)                 = 2
read(3, "\x33", 1)                      = 1
write(3, "\xc0\x01", 2)                 = 2
read(3, "\x31", 1)                      = 1
write(3, "\x70", 1)                     = 1

codehero, 2020-01-22:
Documentation has been updated as per issue #30 . No more need for this issue

Closed 2020-01-22.

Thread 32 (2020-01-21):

i2ccl: Monitor mode not working

codehero, 2020-01-21:
Using i2ccl on Pi Zero and i2cddriver connected by USB to try and monitor i2c traffic between Pi and device.
Invoking: `strace ./build/i2ccl /dev/ttyUSB0 m`

I see the I2C traffic picked up on the LCD but not passed back through USB.
This is not terribly helpful given the volume of traffic I have to look through.

strace output

```
execve("./build/i2ccl", ["./build/i2ccl", "/dev/ttyUSB0", "m"], [/* 17 vars */]) = 0
brk(0)                                  = 0xed4000
uname({sys="Linux", node="RAD-TESTER-000", ...}) = 0
access("/etc/ld.so.nohwcap", F_OK)      = -1 ENOENT (No such file or directory)
mmap2(NULL, 8192, PROT_READ|PROT_WRITE, MAP_PRIVATE|MAP_ANONYMOUS, -1, 0) = 0xb6fa2000
access("/etc/ld.so.preload", R_OK)      = 0
open("/etc/ld.so.preload", O_RDONLY|O_CLOEXEC) = 3
fstat64(3, {st_mode=S_IFREG|0644, st_size=42, ...}) = 0
mmap2(NULL, 42, PROT_READ|PROT_WRITE, MAP_PRIVATE, 3, 0) = 0xb6fa1000
close(3)                                = 0
open("/usr/lib/arm-linux-gnueabihf/libarmmem.so", O_RDONLY|O_CLOEXEC) = 3
read(3, "\177ELF\1\1\1\0\0\0\0\0\0\0\0\0\3\0(\0\1\0\0\0h\5\0\0004\0\0\0"..., 512) = 512
lseek(3, 17960, SEEK_SET)               = 17960
read(3, "\0\0\0\0\0\0\0\0\0\0\0\0\0\0\0\0\0\0\0\0\0\0\0\0\0\0\0\0\0\0\0\0"..., 960) = 960
lseek(3, 17696, SEEK_SET)               = 17696
read(3, "A.\0\0\0aeabi\0\1$\0\0\0\0056\0\6\6\10\1\t\1\n\3\f\1\22\4\24"..., 47) = 47
fstat64(3, {st_mode=S_IFREG|0644, st_size=18920, ...}) = 0
mmap2(NULL, 83236, PROT_READ|PROT_EXEC, MAP_PRIVATE|MAP_DENYWRITE, 3, 0) = 0xb6f60000
mprotect(0xb6f65000, 61440, PROT_NONE)  = 0
mmap2(0xb6f74000, 4096, PROT_READ|PROT_WRITE, MAP_PRIVATE|MAP_FIXED|MAP_DENYWRITE, 3, 0x4000) = 0xb6f74000
mprotect(0xbe841000, 4096, PROT_READ|PROT_WRITE|PROT_EXEC|PROT_GROWSDOWN) = 0
close(3)                                = 0
munmap(0xb6fa1000, 42)                  = 0
open("/usr/local/lib/mspdebug/tls/v6l/vfp/libc.so.6", O_RDONLY|O_CLOEXEC) = -1 ENOENT (No such file or directory)
stat64("/usr/local/lib/mspdebug/tls/v6l/vfp", 0xbe83fe00) = -1 ENOENT (No such file or directory)
open("/usr/local/lib/mspdebug/tls/v6l/libc.so.6", O_RDONLY|O_CLOEXEC) = -1 ENOENT (No such file or directory)
stat64("/usr/local/lib/mspdebug/tls/v6l", 0xbe83fe00) = -1 ENOENT (No such file or directory)
open("/usr/local/lib/mspdebug/tls/vfp/libc.so.6", O_RDONLY|O_CLOEXEC) = -1 ENOENT (No such file or directory)
stat64("/usr/local/lib/mspdebug/tls/vfp", 0xbe83fe00) = -1 ENOENT (No such file or directory)
open("/usr/local/lib/mspdebug/tls/libc.so.6", O_RDONLY|O_CLOEXEC) = -1 ENOENT (No such file or directory)
stat64("/usr/local/lib/mspdebug/tls", 0xbe83fe00) = -1 ENOENT (No such file or directory)
open("/usr/local/lib/mspdebug/v6l/vfp/libc.so.6", O_RDONLY|O_CLOEXEC) = -1 ENOENT (No such file or directory)
stat64("/usr/local/lib/mspdebug/v6l/vfp", 0xbe83fe00) = -1 ENOENT (No such file or directory)
open("/usr/local/lib/mspdebug/v6l/libc.so.6", O_RDONLY|O_CLOEXEC) = -1 ENOENT (No such file or directory)
stat64("/usr/local/lib/mspdebug/v6l", 0xbe83fe00) = -1 ENOENT (No such file or directory)
open("/usr/local/lib/mspdebug/vfp/libc.so.6", O_RDONLY|O_CLOEXEC) = -1 ENOENT (No such file or directory)
stat64("/usr/local/lib/mspdebug/vfp", 0xbe83fe00) = -1 ENOENT (No such file or directory)
open("/usr/local/lib/mspdebug/libc.so.6", O_RDONLY|O_CLOEXEC) = -1 ENOENT (No such file or directory)
stat64("/usr/local/lib/mspdebug", {st_mode=S_IFDIR|S_ISGID|0755, st_size=4096, ...}) = 0
open("/etc/ld.so.cache", O_RDONLY|O_CLOEXEC) = 3
fstat64(3, {st_mode=S_IFREG|0644, st_size=42459, ...}) = 0
mmap2(NULL, 42459, PROT_READ, MAP_PRIVATE, 3, 0) = 0xb6f97000
close(3)                                = 0
access("/etc/ld.so.nohwcap", F_OK)      = -1 ENOENT (No such file or directory)
open("/lib/arm-linux-gnueabihf/libc.so.6", O_RDONLY|O_CLOEXEC) = 3
read(3, "\177ELF\1\1\1\0\0\0\0\0\0\0\0\0\3\0(\0\1\0\0\0L\204\1\0004\0\0\0"..., 512) = 512
lseek(3, 1239936, SEEK_SET)             = 1239936
read(3, "\0\0\0\0\0\0\0\0\0\0\0\0\0\0\0\0\0\0\0\0\0\0\0\0\0\0\0\0\0\0\0\0"..., 2840) = 2840
lseek(3, 1236500, SEEK_SET)             = 1236500
read(3, "A.\0\0\0aeabi\0\1$\0\0\0\0056\0\6\6\10\1\t\1\n\2\22\4\23\1\24"..., 47) = 47
fstat64(3, {st_mode=S_IFREG|0755, st_size=1242776, ...}) = 0
mmap2(NULL, 1312152, PROT_READ|PROT_EXEC, MAP_PRIVATE|MAP_DENYWRITE, 3, 0) = 0xb6e1f000
mprotect(0xb6f4a000, 65536, PROT_NONE)  = 0
mmap2(0xb6f5a000, 12288, PROT_READ|PROT_WRITE, MAP_PRIVATE|MAP_FIXED|MAP_DENYWRITE, 3, 0x12b000) = 0xb6f5a000
mmap2(0xb6f5d000, 9624, PROT_READ|PROT_WRITE, MAP_PRIVATE|MAP_FIXED|MAP_ANONYMOUS, -1, 0) = 0xb6f5d000
close(3)                                = 0
mmap2(NULL, 4096, PROT_READ|PROT_WRITE, MAP_PRIVATE|MAP_ANONYMOUS, -1, 0) = 0xb6f96000
set_tls(0xb6f964c0, 0xb6f96ba8, 0xb6fa5058, 0xb6f964c0, 0xb6fa5058) = 0
mprotect(0xb6f5a000, 8192, PROT_READ)   = 0
mprotect(0xb6f60000, 20480, PROT_READ|PROT_WRITE) = 0
mprotect(0xb6f60000, 20480, PROT_READ|PROT_EXEC) = 0
cacheflush(0xb6f60000, 0xb6f65000, 0, 0x15, 0xbe8402e8) = 0
mprotect(0xb6fa4000, 4096, PROT_READ)   = 0
munmap(0xb6f97000, 42459)               = 0
open("/dev/ttyUSB0", O_RDWR|O_NOCTTY)   = 3
ioctl(3, SNDCTL_TMR_TIMEBASE or SNDRV_TIMER_IOCTL_NEXT_DEVICE or TCGETS, {B1000000 -opost -isig -icanon -echo ...}) = 0
ioctl(3, SNDCTL_TMR_TIMEBASE or SNDRV_TIMER_IOCTL_NEXT_DEVICE or TCGETS, {B1000000 -opost -isig -icanon -echo ...}) = 0
ioctl(3, SNDCTL_TMR_START or SNDRV_TIMER_IOCTL_TREAD or TCSETS, {B1000000 -opost -isig -icanon -echo ...}) = 0
ioctl(3, SNDCTL_TMR_TIMEBASE or SNDRV_TIMER_IOCTL_NEXT_DEVICE or TCGETS, {B1000000 -opost -isig -icanon -echo ...}) = 0
write(3, "@@@@@@@@@@@@@@@@@@@@@@@@@@@@@@@@"..., 64) = 64
write(3, "eA", 2)                       = 2
read(3, "A", 1)                         = 1
write(3, "e\r", 2)                      = 2
read(3, "\r", 1)                        = 1
write(3, "e\n", 2)                      = 2
read(3, "\n", 1)                        = 1
write(3, "e\0", 2)                      = 2
read(3, "\0", 1)                        = 1
write(3, "?", 1)                        = 1
read(3, "[i2cdriver1 DO01JT5U 000000017 5"..., 80) = 80
write(3, "m", 1)                        = 1
fstat64(1, {st_mode=S_IFCHR|0620, st_rdev=makedev(136, 1), ...}) = 0
mmap2(NULL, 4096, PROT_READ|PROT_WRITE, MAP_PRIVATE|MAP_ANONYMOUS, -1, 0) = 0xb6fa1000
write(1, "[Hit return to exit monitor mode"..., 34[Hit return to exit monitor mode]
) = 34
fstat64(0, {st_mode=S_IFCHR|0620, st_rdev=makedev(136, 1), ...}) = 0
mmap2(NULL, 4096, PROT_READ|PROT_WRITE, MAP_PRIVATE|MAP_ANONYMOUS, -1, 0) = 0xb6fa0000
read(0,

```

codehero, 2020-01-21:
Misunderstood diff between capture and monitor

Closed 2020-01-21.

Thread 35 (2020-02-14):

Enumerate as a Linux device

sako0938, 2020-02-14:
Is it possible to use the i2cdriver like a native I2C port, enumerated in /dev/i2c-*?

On my Raspberry Pi, I use the Python smbus2 library to control I2C devices. I would love to be able to plug the I2CDriver into my computer and ran the same exact code as on the Raspberry Pi.

codehero, 2020-02-19:
You could take a stab at writing a CUSE driver

jamesbowman, 2020-02-24:
Looking around, it seems that CUSE is not very actively developed.

sako0938, 2020-02-24:
Thanks, I also briefly looked into CUSE to see what it would take. I'm a little ways off before I can devote some time to this, but I'm definitely very interested so I hope to get a chance to take a stab at it.

mickeyl, 2021-12-21:
Any update on that? Just stumbled over the same "limitation".

mbenkmann, 2021-12-23:
Maybe a firmware for i2cdriver could be developed that is compatible with the simple device supported by this Linux driver:

/usr/src/linux/drivers/i2c/busses/i2c-tiny-usb.c

which is for this device

https://github.com/harbaum/I2C-Tiny-USB

mickeyl, 2021-12-23:
Indeed, that would be pretty cool. While I can work around the difference of talking to the I2CDriver vs. the I2C character device with an additional abstraction layer in my programs, it would be much nicer if that wasn't necessary.

mbenkmann, 2021-12-27:
Unfortunately my idea does not seem possible because the USB frontend of the i2cdriver is provided by an FTDI chip and is therefore hardwired to be a USB serial device, so the USB protocol can't be changed. But I have a different idea. One could take the kernel driver ftdi_sio which handles the FTDI chip and add support for the I2C-related ioctls. The first time an I2C ioctl is used, the driver engages a translation layer that translates read()/write() data blocks from/to the i2cdrive's protocol. Finally you write a udev-rule that creates a symlink from /dev/i2c-... to /dev/ttyUSB...

The result would be that programs that use /dev/i2c-... would just work on the i2c-driver's device even though it's not a real i2c-bus from the Linux kernel's perspective because every i2c program always has an i2c-related ioctl before the first read()/write(), thereby activating the translation layer. Since the translation layer is active on a per-file descriptor basis, you can mix and match programs that use i2cdriver's native interface and those that use the i2c interface as you wish. E.g. you could use stm32flash to program an STM32 MCU via the i2cdriver and then without having to unplug/reset/whatever start the I2C driver's python helper program to debug the I2C bus functionality of your STM32.

mbenkmann, 2022-01-14:
I'm seriously looking into working on this. Has anyone else started on this? I'm still looking for the best option. I think I will try a CUSE solution first.
@kornpow You said you looked into CUSE. How far did you get? I'm at the point where I've googled it and am looking at the top search results. Did you get further into the topic?

mickeyl, 2022-01-14:
This would be frickin' awesome. Crossing fingers that you can make it happen!

kornpow, 2022-01-14:
No I didn’t get too far, and haven’t been doing to much embedded systems lately but would love anything that makes using I2C on normal laptops easier!

mbenkmann, 2022-01-24:
Okay. I've implemented the CUSE-based solution. You can find it here:

https://github.com/mbenkmann/i2cdriver/tree/master/c/linux

The program also includes a more powerful command line interface to all other features of the i2cdriver, so if you're on Linux this should be an all around better replacement for the bare bones i2ccl utility.

So far I've only implemented the pure i2c ioctls that are used e.g. by i2ctransfer(8) and stm32flash(1) but it's easy to add the SMBus-related stuff, too, so if you have a concrete need for it, open an issue.

kornpow, 2022-01-25:
Not that I am going to use this any time soon, but IMO since you are already in there, why not add SMBus related stuff? Save someone the realization that what theyre trying to do is unimplemented.

codehero, 2022-01-25:
This is really cool, thanks! If I weren't so busy with other projects I would make a different i2cdriver device that wasn't written in (colorforth?)

Does this have a configurable clock stretch timeout?

(also issues don't seem to be enabled on your fork)

mbenkmann, 2022-01-25:
Thanks for pointing that out. I wasn't aware that Issues weren't enabled by default. I enabled them now.
As for clock stretching, I'm not seeing a command to configure this in the i2cdriver manual.

jamesbowman, 2022-01-25:
@codehero @mbenkmann is correct, there is no clock stretch timeout configuration value. iirc it's set to something like 250 ms.

@codehero is written in myForth, a machineForth-flavored Forth for 8051s. http://www.kiblerelectronics.com/myf/myf.shtml

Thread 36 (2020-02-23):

When connected, i2cbusses merge

jessica-mulein, 2020-02-23:
I have a raspberry pi and had attempted to inspect bus i2c-1 and i2c-6. When connected, device 0x22 on i2c-6 joined bus 1 and vice-versa, according to i2cdetect on my pi-host. Didn't seem to matter whether powered on or not/connected to my Macbook host I intended to inspect from.

Normal:
➜  ~ /usr/sbin/i2cdetect -y 1
     0  1  2  3  4  5  6  7  8  9  a  b  c  d  e  f
00:          -- -- -- -- -- -- -- -- -- -- -- -- --
10: -- -- -- -- -- -- -- -- -- -- -- -- 1c -- -- --
20: -- -- -- -- -- -- -- -- -- -- -- -- -- -- -- --
30: -- -- -- -- -- -- -- -- -- -- -- -- -- -- -- --
40: -- -- -- -- -- -- -- -- -- -- -- -- -- -- -- --
50: -- -- -- -- -- -- -- -- -- -- -- -- -- -- -- --
60: -- -- -- -- -- -- -- -- -- -- 6a -- -- -- -- --
70: -- -- -- -- -- -- -- 77
➜  ~ /usr/sbin/i2cdetect -y 6
     0  1  2  3  4  5  6  7  8  9  a  b  c  d  e  f
00:          -- -- -- -- -- -- -- -- -- -- -- -- --
10: -- -- -- -- -- -- -- -- -- -- -- -- -- -- -- --
20: -- -- 22 -- -- -- -- -- -- -- -- -- -- -- -- --
30: -- -- -- -- -- -- -- -- -- -- -- -- -- -- -- --
40: -- -- -- -- -- -- -- -- -- -- -- -- -- -- -- --
50: -- -- -- -- -- -- -- -- -- -- -- -- -- -- -- --
60: -- -- -- -- -- -- -- -- -- -- -- -- -- -- -- --
70: -- -- -- -- -- -- -- --

When connected:
➜  ~ /usr/sbin/i2cdetect -y 6
     0  1  2  3  4  5  6  7  8  9  a  b  c  d  e  f
00:          -- -- -- -- -- -- -- -- -- -- -- -- --
10: -- -- -- -- -- -- -- -- -- -- -- -- 1c -- -- --
20: -- -- 22 -- -- -- -- -- -- -- -- -- -- -- -- --
30: -- -- -- -- -- -- -- -- -- -- -- -- -- -- -- --
40: -- -- -- -- -- -- -- -- -- -- -- -- -- -- -- --
50: -- -- -- -- -- -- -- -- -- -- -- -- -- -- -- --
60: -- -- -- -- -- -- -- -- -- -- 6a -- -- -- -- --
70: -- -- -- -- -- -- -- 77
➜  ~ /usr/sbin/i2cdetect -y 1
     0  1  2  3  4  5  6  7  8  9  a  b  c  d  e  f
00:          -- -- -- -- -- -- -- -- -- -- -- -- --
10: -- -- -- -- -- -- -- -- -- -- -- -- 1c -- -- --
20: -- -- 22 -- -- -- -- -- -- -- -- -- -- -- -- --
30: -- -- -- -- -- -- -- -- -- -- -- -- -- -- -- --
40: -- -- -- -- -- -- -- -- -- -- -- -- -- -- -- --
50: -- -- -- -- -- -- -- -- -- -- -- -- -- -- -- --
60: -- -- -- -- -- -- -- -- -- -- 6a -- -- -- -- --
70: -- -- -- -- -- -- -- 77

jamesbowman, 2020-02-23:
Please can you show how the I2CDriver is connected?

One thing to mention is that the 3 ports on the I2CDriver are all physically wired together - they're not separate I2C busses. So when multiple things are connected to I2CDriver, they are all connected together.

jessica-mulein, 2020-02-24:
No, I suppose it makes sense. I looked at it and expected to be able to read 4 separate busses at a time, but those connectors are really more about the output or perhaps separate circuits... Do you suppose you will have a version in the future that doesn't jumper those together so I could record both streams without two devices?

jamesbowman, 2020-02-24:
Makes sense.

For multiple buses the best setup is multiple I2CDrivers -- they are designed to all work well on the same host. I2C Minis are functionally identical (capture mode is supported), and are available in multiples.

https://i2cdriver.com/mini.html

Closed 2020-02-24.

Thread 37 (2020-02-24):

SCL low period timing too small?

Sabine-Schnabeltier, 2020-02-24:
According to table 10 of the [I2C specification](https://www.nxp.com/docs/en/user-guide/UM10204.pdf), for 100 kHz operation, SCL has a minimum low period of 4.7 us and a minimum high period of 4.0 us.

Checking the signals generated by the I²CDriver board, SCL is low for roughly 3.5 us and high for the remaining time of the 10 us clock cycle.

The I2C devices I am trying to control specify a 4.7 us clock low time and I suspect that this timing issue may be the reason I am unable to control them.

jamesbowman, 2020-02-24:
Yes, from the I2C is a hardware block in the EFM8BB1 microntroller:

https://www.silabs.com/documents/public/reference-manuals/efm8bb1-rm.pdf

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

And there they confirm it. "SCL ... THIGH is typically twice as large as TLOW." Which is very close to what you measured.

I will ask about this on the Silicon Labs support forum. It seems quite clear that if configured for 100 and 400 KHz I2C would be out of spec. This is surprising for an automotive-rated part.

Unfortunately I don't really think there is much that can be done on this. Are you able to say what the I2C device is?

Sabine-Schnabeltier, 2020-02-24:
It is the Cirrus Logic [CS2300-CP](https://4donline.ihs.com/images/VipMasterIC/IC/CIRR/CIRR-S-A0001393877/CIRR-S-A0001393877-1.pdf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).

jamesbowman, 2020-02-24:
OK, thanks. I have ordered one from Digikey. I should be able to confirm it in 3-4 days.

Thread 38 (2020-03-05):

Clock stretching?

jessica-mulein, 2020-03-05:
Can you tell me about anything I need to do specifically to handle clock stretching? What is supported? I'm switching from the Raspberry Pi's internal I2c circuit to yours hoping to avoid issues with that- but will I? the RPI supports clock stretching during ACK but i keep getting the famous i2c lockouts.

jamesbowman, 2020-03-07:
Apologies, I missed this. Clock stretching is fully supported by the I2CDriver, and is always enabled.  There's nothing to enable.

Closed 2020-03-06.

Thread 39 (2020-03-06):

clang/clang++ in -c++17 mode generates cast error

jessica-mulein, 2020-03-06:
src/i2cdriver/c/common/i2cdriver.c:326:28: note: insert an explicit cast to silence this issue
  uint8_t start[2] = {'s', (dev << 1) | op};
                           ^~~~~~~~~~~~~~~
                           static_cast<uint8_t>( )

jessica-mulein, 2020-03-06:
You are a speedy demon.

Closed 2020-03-06.

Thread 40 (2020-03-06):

MacOS- TCSANOW, Serial settings: Invalid argument

jessica-mulein, 2020-03-06:
//            i2c_connect(&i2cDriver, "/dev/tty.usbserial-DO029HL5");
            i2c_connect(&i2cDriver, "/dev/cu.usbserial-DO029HL5");

bombs out  at the tcsetatttr call on my mac os Catalina machine
  cfmakeraw(&Settings);
  Settings.c_cc[VMIN] = 1;
  if (tcsetattr(fd, TCSANOW, &Settings) != 0) {
      perror("Serial settings");
    return -1;
  }

Right now my code runs and I can i2c_scan just fine, but my i2c_write's and read's are not working

Any ideas?

jessica-mulein, 2020-03-06:
I've actually also discovered that at least some of my problem seems to be with the 3 SparkFun Qwiic LED Sticks plugged into an i2cmini

// i2cdriver has a few things
 ✘    master ●  ./i2ccl /dev/cu.usbserial-DO029HL5 d

--  --  --  --  --  --  --  --
--  --  --  --  --  --  --  --
--  --  --  --  --  --  --  --
--  --  --  --  --  --  26  --
--  --  --  --  --  --  --  --
--  --  --  --  --  --  --  --
--  --  --  --  --  --  --  --
--  --  42  --  --  --  --  --
--  --  --  --  --  --  --  --
--  --  --  --  --  --  --  --
--  --  --  5b  --  --  --  --
--  --  --  --  --  --  --  --
--  --  --  --  --  --  --  --
--  --  --  --  --  --  --  77

// i2cmini connected to LED sticks
 ✘    master ●  ./i2ccl /dev/cu.usbserial-DO029ICO d

never returns

The i2c-mini is connected directly to a string of 3 qwiic LED sticks with nothing else on the line.  Colors are matched up.

jessica-mulein, 2020-03-07:
I'm actually having a really hard time just with i2ccl being unreliable on a line connected directly to three SparkFun Qwiic LED stix using only the short leads provided (less than 12in total wire). I've only gotten this to show up once
```
 ✘   master ●  ./i2ccl /dev/cu.usbserial-DO029ICO d

--  --  --  --  --  --  --  --
--  --  --  --  --  --  --  --
--  --  --  --  --  --  --  --
--  --  22  23  24  --  --  --
--  --  --  --  --  --  --  --
--  --  --  --  --  --  --  --
--  --  --  --  --  --  --  --
--  --  --  --  --  --  --  --
--  --  --  --  --  --  --  --
--  --  --  --  --  --  --  --
--  --  --  --  --  --  --  --
--  --  --  --  --  --  --  --
--  --  --  --  --  --  --  --
--  --  --  --  --  --  --  --
```
some things just don't respond most of the time
```
 ✘    master ●  ./i2ccl /dev/cu.usbserial-DO029ICO x
^C
 ✘    master ●  ./i2ccl /dev/cu.usbserial-DO029ICO i
^C
 ✘    master ●  ./i2ccl /dev/cu.usbserial-DO029ICO x
^C
```
after unplugging the USB and trying again (have tried different cables too):
```
 ✘    master ●  ./i2ccl /dev/cu.usbserial-DO029ICO i
uptime 43  5.000 V  0 mA  27.5 C SDA=1 SCL=1 speed=100 kHz
 ✘   master ●  ./i2ccl /dev/cu.usbserial-DO029ICO d
(...never returns again)
```

Any idea what could be going on?

jamesbowman, 2020-03-07:
That's very strange. My immediate reaction to this kind of thing is to get one to add to the test set, but I see theQwiic LED strips is out of stock.

(1) Maybe the LEDs are drawing so much current that they crash the I2CMini? Maybe connect VCC to a seperate  3.3V supply? Try it with an I2CDriver to view the current measurement. At startup, are all-off or all-on?

(2) On its Sparkfun page people are reporting the the stick itself locks up the I2C bus - buggy firmware. Could it be that the address-scan is putting it into a buggy state? I notice that their library only does I2C writes:

https://github.com/sparkfun/SparkFun_Qwiic_LED_Stick_Arduino_Library/blob/master/src/Qwiic_LED_Stick.cpp

Maybe power-up, and do a single write, copying their code for [setLEDColor](https://github.com/sparkfun/SparkFun_Qwiic_LED_Stick_Arduino_Library/blob/master/src/Qwiic_LED_Stick.cpp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):

i2ccl /dev/cu.usbserial-DO029ICO w 0x23 0x72,0x00,0xff,0x00 p

meaning COMMAND_WRITE_ALL_LED_COLOR,0,255,0. It should set all LEDs to green.

jessica-mulein, 2020-03-07:
Switching the configuration around, I can enumerate it on the full i2cdriver repeatedly

   master ●  ./i2ccl /dev/cu.usbserial-DO029HL5 d

--  --  --  --  --  --  --  --
--  --  --  --  --  --  --  --
--  --  --  --  --  --  --  --
--  --  22  23  24  --  --  --
--  --  --  --  --  --  --  --
--  --  --  --  --  --  --  --
--  --  --  --  --  --  --  --
--  --  --  --  --  --  --  --
--  --  --  --  --  --  --  --
--  --  --  --  --  --  --  --
--  --  --  --  --  --  --  --
--  --  --  --  --  --  --  --
--  --  --  --  --  --  --  --
--  --  --  --  --  --  --  --

   master ●  ./i2ccl /dev/cu.usbserial-DO029HL5 d

--  --  --  --  --  --  --  --
--  --  --  --  --  --  --  --
--  --  --  --  --  --  --  --
--  --  22  23  24  --  --  --
--  --  --  --  --  --  --  --
--  --  --  --  --  --  --  --
--  --  --  --  --  --  --  --
--  --  --  --  --  --  --  --
--  --  --  --  --  --  --  --
--  --  --  --  --  --  --  --
--  --  --  --  --  --  --  --
--  --  --  --  --  --  --  --
--  --  --  --  --  --  --  --
--  --  --  --  --  --  --  --
```
and more..

Maybe the i2cmini is different?

jamesbowman, 2020-03-07:
I2CDriver and I2CMini are build from the same code base. What does 'i' report as the current usage?

jessica-mulein, 2020-03-07:
Yeah that's about what I'm seeing. Sweet.. so.. it's not your problem.

```
   master ●  ./i2ccl /dev/cu.usbserial-DO029ICO i
uptime 2294  5.000 V  0 mA  35.2 C SDA=1 SCL=1 speed=100 kHz
   master ●  ./i2ccl /dev/cu.usbserial-DO029HL5 i
uptime 7841  5.240 V  10 mA  28.7 C SDA=1 SCL=1 speed=100 kHz
```
LED sticks on the latter.

jessica-mulein, 2020-03-07:
None of these were successful in lighting up any LEDs off the i2cdriver full :/ even after a full power on reset. *shrug* OK well- moving on without the LED's in my project I think then!
```
   master ●  ./i2ccl /dev/cu.usbserial-DO029HL5 w 0x23 0x72,0x00,0xff,0x00 p
   master ●  ./i2ccl /dev/cu.usbserial-DO029HL5 w 0x23 0x72,0x00,0xff,0x00 p
   master ●  ./i2ccl /dev/cu.usbserial-DO029HL5 w 0x23 0x72,0x00,0xff,0x00 p
   master ●  ./i2ccl /dev/cu.usbserial-DO029HL5 w 0x22 0x72,0x00,0xff,0x00 p
   master ●  ./i2ccl /dev/cu.usbserial-DO029HL5 w 0x24 0x72,0x00,0xff,0x00 p
   master ●  ./i2ccl /dev/cu.usbserial-DO029HL5 w 0x24 0x72,0x00,0xff,0x00 p
   master ●  ./i2ccl /dev/cu.usbserial-DO029HL5 w 0x24 0x72,0x00,0xff,0x00 p
```

jessica-mulein, 2020-03-07:
If you have an email address you don't mind me sending a photo of the setup to, I can do so (with the output on the screen of the i2cdriver full)[](url)

jamesbowman, 2020-06-01:
Seems like the peripheral is locking up - and Sparkfun retired it so there's no obvious way of debugging this.

OK to close?

jessica-mulein, 2020-06-01:
Yep!

Closed 2020-06-01.

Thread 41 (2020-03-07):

Does not run on Windows 10 x64

Kabron287, 2020-03-07:
6 releases and it does not work!
Windows 10 x64 LTSC. Two processes in Task manager do nothing.
Cmpatibility/Admin Rights not help.

CLI not better
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

jamesbowman, 2020-03-07:
When you say "two processes in Task manager" are these old I2CDriver GUI processes?

Maybe kill them or reboot, and try running the GUI again?

Kabron287, 2020-03-08:
Each launch creates two processes. The second one waits for the first.
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

Closed 2020-11-27.

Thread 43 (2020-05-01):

A Life Saver

mgaman, 2020-05-01:
Such a handy tool, thanks a million.
It helped me to debug a situation where the I2C device documentation was incorrect. Saved me from a lot of aggravation and frustration.

jamesbowman, 2020-06-01:
Awesome. Glad it helped - closing!

Closed 2020-06-01.

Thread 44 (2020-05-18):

IndexError if no IO connected

markddavidoff, 2020-05-18:
```
>>> i2cdriver.I2CDriver("/dev/tty.usbserial-DO02C6S9").scan()
Traceback (most recent call last):
  File "<stdin>", line 1, in <module>
  File "/usr/local/lib/python3.7/site-packages/i2cdriver.py", line 109, in __init__
    r = self.__echo(c)
  File "/usr/local/lib/python3.7/site-packages/i2cdriver.py", line 140, in __echo
    return r[0]
IndexError: index out of range
```

jamesbowman, 2020-05-18:
It looks like the I2CDriver has hung at this point. That's why the initial 'echo' check fails. Pretty fundamental.

Starting from a freshly plugged-in I2CDriver, what gets it into this hung state? Or does it do this immediately after power-on?

markddavidoff, 2020-05-18:
I get this anytime something is not plugged into the i2cdriver, immediatley after power on. if i have something connected i'll get the  i2c grid output.

jamesbowman, 2020-05-18:
Interesting. It might be a hardware problem with the I2CDriver's pullup resistors. If you do (from a fresh power-on with nothing connected):

    i2 = i2cdriver.I2CDriver("/dev/tty.usbserial-DO02C6S9")
    i2.setpullups(0x3f)
    i2.scan()

do you see the same issue?

markddavidoff, 2020-05-21:
thanks for the quick response and sorry for the delay, here's the output i get:
yeah seems to be outputting :
```
-- -- -- -- -- -- -- --
-- -- -- -- -- -- -- --
-- -- -- -- -- -- -- --
-- -- -- -- -- -- -- --
-- -- -- -- -- -- -- --
-- -- -- -- -- -- -- --
-- -- -- -- -- -- -- --
-- -- -- -- -- -- -- --
-- -- -- -- -- -- -- --
-- -- -- -- -- -- -- --
-- -- -- -- -- -- -- --
-- -- -- -- -- -- -- --
-- -- -- -- -- -- -- --
-- -- -- -- -- -- -- --
[]
```
consistently now, odd, because i was getting that error consistently before as well. thanks!

jamesbowman, 2020-06-01:
OK, thanks. Closing.

Closed 2020-06-01.

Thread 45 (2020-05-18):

struct.error: unpack requires a buffer of 112 bytes

markddavidoff, 2020-05-18:
```
>>> i2cdriver.I2CDriver("/dev/tty.usbserial-DO02C6S9").scan()
Traceback (most recent call last):
  File "<stdin>", line 1, in <module>
  File "/usr/local/lib/python3.7/site-packages/i2cdriver.py", line 188, in scan
    d = struct.unpack("112c", self.ser.read(112))
struct.error: unpack requires a buffer of 112 bytes
```

markddavidoff, 2020-05-21:
can no longer repro /shrug

Closed 2020-05-21.

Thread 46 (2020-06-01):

Difficulty using with Mac OS X 10.15.5

joshrawls, 2020-06-01:
I had this working at one time, but it's been awhile.

At first it was only showing up as a "Composite Device" in System Information. I re-installed the FTDI drivers and now it shows up as "FT230X Basic UART" so I think I'm making some progress.

When I try to load the GUI no device shows in the drop-down area to select the I2CDriver com port.

What else am I missing? Keep in mind I'm a Linux/newb so if you have command line instructions for me please let me know what each command is doing so I can learn while I fix.

Thanks!

joshrawls, 2020-06-01:
I have an addition concerning Windows 10 Pro 64-bit.

I can get the device to show up as a "USB Serial Converter" in Device Manager, so I think I have the drivers installed correctly.

I installed the Windows version of I2CDriver and I have the same results as on the Mac. No device shown in the drop-down menu.

What am I doing wrong in both OS's?

jamesbowman, 2020-06-01:
Does the serial number in Device Manager match the one on the bottom of the I2CDriver?

joshrawls, 2020-06-01:
It shows the correct serial number in System Information.

I was able to get it working on a separate Windows 10 laptop. So I know the device is still good, but this isn't a permanent solution. On that laptop it shows up in Device Manager as a COM3 port and does not show the serial number anywhere I could find. I'm also not super familiar with Windows 10 so I may be missing it somewhere.

Update: I just looked for it as a COM port on my other Windows install that wasn't previously working. It was showing as COM5 but wouldn't show up in the GUI. I changed it to COM6 and now it is working under windows. Still no luck on the Mac.

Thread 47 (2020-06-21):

Trying to run i2cDriver.exe on windows 10

txf-, 2020-06-21:
I installed the application using the installer. Unfortunately I have issues using it.

Either the application window does not appear, but the app remains running in the process list.

Or the application window does show up but I can't actually select any COM ports.
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

jamesbowman, 2020-06-22:
OK, there seem to be two issues here.

1. Running the current i2cgui.py Python doesn't connect to COM ports

2. The packaged version of the GUI does not launch reliably

Can we start with (1)... a few quick questions

 * what version of Windows are you running this on?
 * when you run i2ccl.exe, do you get output for the "i" command, e.g.
       ```i2ccl.exe COM6 i```
 * are there other serial devices attached?

scottbob09, 2020-06-23:
uptime 365  4.856 V  15 mA  30.6 C SDA=0 SCL=1 speed=100 kHz

jamesbowman, 2020-06-24:
OK, thanks.

When you start the GUI on the command-line, you can supply the port, which avoids the GUI's discovery process, e.g.

    python i2cgui.py COM6

This should be worth a try.

txf-, 2020-06-24:
Supplying the com port as an argument works

scottbob09, 2020-06-25:
For me as well

madgrizzle, 2021-01-28:
I have the same issue with the Windows 10 application.  Is there any plans on updating it?  running

`i2ccl.exe COM6 i`

responds fine, but the Windows 10 gui application doesn't populate the comports.

jamesbowman, 2021-01-28:
If you start the gui with the port on the command-line

    i2cgui COM6

does it work?

madgrizzle, 2021-01-28:
I will try tonight.  I've only tried using the windows icon.

vonkonow, 2021-02-01:
I’m having the same problem. Port won’t show up in gui. Doesn’t help if I run "i2cgui COM7"
(“i2ccl.exe COM7 I” works: “uptime 6  5.167 V  0 mA  25.9 C SDA=1 SCL=1 speed=100 kHz”)

jamesbowman, 2021-02-01:
@vonkonow

When you run "i2cgui COM7" from the command-line, what does it do?

vonkonow, 2021-02-02:
> @vonkonow
>
> When you run "i2cgui COM7" from the command-line, what does it do?

The program started, but port was empty (like the first image in this thread). However after running the program as admin and a reboot later, everything seems to work fine now.

RoryMacKean, 2021-04-17:
I'm seeing the same issue as @vonkonow and @madgrizzle.

I'm running Windows 10 (in VirtualBox, on a Mac Catalina host).
`i2ccl COM3 i` returns:
`uptime 448  5.152 V  0 mA  28.2 C SDA=0 SCL=0 speed=100 kHz`

but when I run the gui, either by double-clicking or running `i2cgui COM3` I get an image the same as the one at the top.  This also happens if I try those things as Administrator.

Unfortunately for me, though, a reboot hasn't fixed the issue.

MarkLuinenburg, 2021-05-25:
Hey all,

I stumbled upon the same issue using windows 10. I went into the device manager , set it up as generic COM port. Then when it was listed there i updated the driver (as it still wasnt working ) with the ft230xq ( https://ftdichip.com/products/ft230xq/ ) driver.

This resolved the issue. So my guess is that windows mislabeled it due to missing drivers. I just forced it to be recognized as an COM port and then allowed the proper driver to interact.

Hope this helps people with similar problems!

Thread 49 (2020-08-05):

No register write command

lukehutch, 2020-08-05:
The I2C Mini has a `register read` command, `'r'`:

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

However, it appears there is no corresponding `register write` command. This seems like a big omission, since many I2C devices that have register values that may be read are controlled by writing to registers.

I realize a similar sequence to the above could be constructed for writing to a register, however it would be great if a command `'w'` could be provided so that this boilerplate could be avoided.

Also, there are no commands for 2-byte register devices in the I2C Mini's firmware. See the different I2C addressing modes and how they are handled on the Devantech USB-ISS device here: https://www.robot-electronics.co.uk/htm/usb_iss_i2c_tech.htm

jamesbowman, 2020-08-05:
Right, here's the `regwr` method that does an explicit start-write-stop:

https://github.com/jamesbowman/i2cdriver/blob/master/python/i2cdriver.py#L305-L329

The I2CDriver's protocol is meant as a 1:1 mapping with the traffic on the I2C bus. So all the "higher-level" protocol handling happens on the host (*).
From my understanding of the USB-ISS, it takes a different approach, where the USB-ISS also knows about register protocols for many I2C devices. (It also offers I2C_DIRECT commands, very much like the I2CDriver). My preference is for systems where the protocol is explicit -- I've had some difficult experiences with schemes that "wrap" protocols up.

Because of the amazing variety in manufacturers' interpretations of I2C, it's very difficult to cover everything. For example some devices need a STOP before the second START in a read register transaction. For example:

https://github.com/jamesbowman/i2cdriver/blob/master/python/samples/qwiic-keypad.py

I don't see how the USB-ISS handles this case. And some I2C capacitive touch panels use 16-bit addresses, but little endian, while the USB-ISS looks like it only supports big-endian.

My point isn't to criticize the USB-ISS, but that building higher-level protocols into the hardware will inevitably be incomplete. You'll always need the low-level protocol. So why not only do that?

(Oof, sorry this is a bit long. Anyway, it's always interesting to see how others do it. Thanks!)

(*) The exception is the 'r' command, of course, which does several operations. The motivation is to avoid USB turnaround times for this very frequent case. But it's a point solution for devices with 8-bit registers that support this RESTART-style addressing.

lukehutch, 2020-08-05:
Makes sense. Well I'd be happy if at least a 'w' command was included for symmetry with the 'r' command, for the common 1-byte register case, where a given number of bytes needs to be written.

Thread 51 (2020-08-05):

i2cdriver.pdf documentation does not cover error code for "transmit status info" command

lukehutch, 2020-08-05:
The documentation at

https://i2cdriver.com/i2cdriver.pdf

specifies that the `'?'` command returns a status string of the form

```
[i2cdriver1 DO01JUOO 000000061 4.971 000 23.8 I 1 1 100 24 ffff ]
```

However, if the I2C Mini gets into some sort of error state, it can return simply

```
1
```

I assume this is an error code? This needs to be documented.

lukehutch, 2020-08-05:
It also seems to return all zeros if the device is still being initialized:

```
00000000000000000000000000000000000000000000000000000000000000000000000000000000
```

jamesbowman, 2020-08-05:
Hmm, the two ends (I2CMini and the host) can get out of sync. Then it gets confusing - the PC doesn't get the response it requests, as above.

From a cold start, sending '?' will always result in the 80-byte status block being returned (p.31).

There is a situation where I2CMini returns a block of zeroes, and that is a "scan devices" command 'd' (p.36). Could it be that a 'd' is sent earlier, and the PC did not read all 112-bytes that 'd' sends back?

lukehutch, 2020-08-05:
For the '1'  response, that's probably what happened.

For the response that was all zeroes, that was right after plugging the device in and immediately running my code from scratch, in which the info command is the first thing to run. So I assume that a scan command is implicitly run on boot?

jamesbowman, 2020-08-05:
Hmm, at boot all the I2CMini does is wait for a command over USB.

This is what the i2ccl does at boot:

https://github.com/jamesbowman/i2cdriver/blob/master/c/common/i2cdriver.c#L243-L269

- First it sends 64 noop ('@') commands, to clear out any partial command that the I2CMini might be executing.
- Then it sends a few echo 'e' commands to confirm the serial port is in sync and running.
- Then it does '?' and parses the resulting status string.

lukehutch, 2020-08-06:
I can't replicate the zeroes behavior, so I'll go ahead and close this.

Closed 2020-08-06.

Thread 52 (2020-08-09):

Feature: setting a default startup mode

jamesbowman, 2020-08-09:
Some users want it always to enter monitor mode, and currently have to use a tool to do it.
It would be good to have a "set default mode" operation that sets it into a particular mode at startup.

A booted i2cdriver in monitor/capture mode goes into mode 'D' as soon as the first character is received.

So a connecting PC's first transmitted character would put it back into driver ('D') mode.

rnsi, 2020-08-10:
I would like this feature. Can you just save the current mode to EEPROM and read it at next boot?

rnsi, 2020-08-10:
And could we also save the pull-ups?

AlvaroHermida, 2020-08-30:
Yes, it will be a great improvement for i2cdriver. Without it, when there is no PC available the device becomes just a dead brick in the toolbox...

jamesbowman, 2020-08-30:
@AlvaroHermida ... one question. How would you power it in this scenario?

rnsi, 2020-08-30:
Usb power pack
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

AlvaroHermida, 2020-08-30:
Yes, these practical power bricks are everywhere nowadays.

fake-name, 2020-09-29:
I don't understand why you'd ever want it to *not* enter monitor mode on power up.

It seems that the device should boot into monitor mode, and only be switched *out* of it by a command. After all, until a host computer talks to it over the serial interface, it's currently useless.

I bought one of these thinking it would operate more like an oscilloscope (e.g. a standalone instrument). If I wanted to have to futz with stuff on my computer to make it work, I'd just use the logic analyzer I already have.

rnsi, 2020-11-22:
Any update on this? I think this is a necessary feature. Thanks.

gardnmc, 2021-01-15:
Hi James, great little device.  Any news on this feature?  To be able to see the results of a bus scan would make this a very useful production pcb testing tool.  Thanks.

hitandrepair, 2021-03-08:
any update on this? would be handy to have for my project. I am using this to check proper wiring for lithium ion batteries for a hospital setting.

rnsi, 2021-03-08:
I'd love to see this.

AlvaroHermida, 2021-03-08:
I'm no longer expecting it...

hitandrepair, 2021-03-08:
> I'd love to see this.

Vendors supplied us batteries with crossed wires. They would work for a day then the medical equipment would shut off and constantly reboot because the clock and data lines were mixed. I initially made the breadboard to fit a certain size but that was wrong. I still have to convert lines around but you get the main idea in how this works. You plug the battery in, and the address of chip blinks. That’s how you know it works. If it doesn’t do anything then the wires are wrong. Pretty cool technology. Vcc from the board is cut off, and without taking the outside shell off, you have no other way of testing this without risking a machine to malfunction. They use this vendor to save about 20k every 2 years. How to test lithium-ion battery clk and sda bus lines with i2c

GOTO-GOSUB, 2021-08-25:
I only ever use mine in monitor mode and would certainly welcome the ability to change its default state.

rnsi, 2021-08-25:
Still holding my breath for this...

rnsi, 2022-01-27:
It's been a while, any chance we can get this feature? I see it's also requested in the comments on the Amazon page. It would be so much more convenient and usable if I didn't have to use a PC just to use monitor mode.

Hoping for an update...

EvanKrall, 2025-08-09:
I'd love to see this -- I also envision myself mostly using the device in monitor mode.

I could take a stab at implementing this myself if there were instructions on how to compile the firmware (#26 / #62).

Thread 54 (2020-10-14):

Bus arbitration

limi97, 2020-10-14:
Can you tell me about anything I need to do specifically to handle bus arbitration? What is supported? If I do the start command the arbitration bit is always set. How can I change this?

jamesbowman, 2020-10-14:
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

This bit should definitely be zero. Being set suggests that either SCL or SDA is tied low. As a first test, I suggest you:

1. remove power from I2CDriver
2. remove all I2C peripherals from I2CDriver
3. apply power to I2CDriver

And check if the **start** still leaves ARB high. If it does, the I2CDriver has a hardware fault, and I can replace it. If not, there is a problem with the I2C peripheral not releasing the bus.

limi97, 2020-10-14:
I tested this. The bit is zero if there is no peripheral connected to the driver. But if I connect a peripheral the bit goes one. I connected several options.

jamesbowman, 2020-10-14:
Aha, thanks. On the software side, are you using the C library, Python, or something else?

jamesbowman, 2020-10-14:
Also (sorry to have to ask this, but it has happened before) have you checked your hookup that SDA and SCL re not swapped? SCL is yellow, SDA is blue.

limi97, 2020-10-14:
Yes I have it the right way. Actually now it works. I did again what you described and now it works perfectly fine.

limi97, 2020-10-14:
Thanks for your help

Closed 2020-10-14.

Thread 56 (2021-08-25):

Hardware Issue with Device - LCD Lifting off PCB

jwshields, 2021-08-25:
Hello,
I'm pretty sure this is not the right place to open a hardware issue for this device, but I've sent an email to the `jamesb at excamera dot com` address and I've not received a response..
I've been experiencing an issue with my I2CDriver where the board flexes a bit much (Maybe it is just me being a brute?) - but if I'm fiddling with it and plugging jumpers in, or the plugging/unplugging the USB cable; when I am doing those things, I seem to see/feel the board flexing in ways which are exerting forces upon the LCD in an unnatural way.  (I also own an SPIDriver and suspect this issue could also happen with that device as well, but I am not experiencing it with my device currently)

A few nights ago when I was using the I2C driver, I noticed that the LCD had lifted off the PCB, because light from the backlight module was leaking out of the sides.

I’ve taken some photos of it, and outlined in red boxes what I’m seeing; in the photos where you see my fingers applying some pressure, I’m doing that to attempt to demonstrate how the LCD is loose and how the leakage of the backlight changes.
The photos are available here: https://file.nouille.party/i2c_driver/

... Onto my actual problem/questions!
- Is this a phenomenon that has been seen before with either the I2C Driver or SPI Driver?
- Are there any recommendations on how to secure the LCD, such that I can do it myself, or what the best thing to do here may be?

Mind, the functionality of the device is not compromised. I just don’t want my LCDs falling off and cracking, or becoming any more loose than what I’m seeing on my I2C Driver. And I am only mentioning the SPI Driver because I feel like it could be possible this issue exists on that board as well.

Thank you in advance, and, I apologize for opening an issue here, as I don't know if this repo is an appropriate place for hardware issues. If so, please feel free to close this issue.

jwshields, 2021-09-02:
I'll try some glue, either thinking I'll try some form of super glue that I can gently dab onto the board. Will post results once I do that.
But... I do hope Mr. Bowman sees this issue and can provide some insight and/or help

GOTO-GOSUB, 2021-09-02:
In the end I used a latex based glue (Copydex) and just ran a little beading of it around the top of the display and a dab in each of the bottom corners then applied just enough pressure to hold the display against the PCB while it dried. So far it's holding up well.

jwshields, 2022-03-23:
Necro'ing this issue a bit. Life has kept me a bit busy..
A few updates:
1. I heard back from James, apparently I completely missed the support email for i2cdriver on the website, but he gave more or less the same pointers as you did @GOTO-GOSUB
2. I tested on both my I2CDriver & SPIDriver boards. I put superglue around the plastic casing that held the LCD on, and superglue between the PCB and the plastic casing. It worked amazingly to secure the LCDs.
3. In my excitement to test things out, I accidentally shorted out gnd and vcc and borked my I2CDriver!

Closing this issue, as, it is technically resolved for me, and the superglue method worked wonderfully, aside from my silly mistake.
Hopefully this can help others in the future though!

Closed 2022-03-23.

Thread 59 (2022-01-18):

I2CDdriver locks up on device scan on unpowered breadboard.

mbenkmann, 2022-01-18:
I noticed that when I do a device scan (d command) while the I2Cdriver is connected to my breadboard (which at present has a Teensy 3.2 and a 24AA256 EEPROM connected to the I2Cbus with 4.7kOhm pullups) but the breadboard is not connected to power the I2CDriver locks up and I need to unplug and replug it to get it to anything again. Or alternatively if I plug in the breadboard, then the I2Cdriver's scan finishes, too.
I noticed this because the Python GUI wouldn't start and I dug deeper into what it does and then I saw that it does a "d" command and analysed it a bit more. It's not a big deal once you know about it, but since I figure it's not that uncommon for people to plug in and start stuff in a different order at times it would be good to catch this condition at some point because otherwise it looks like sometimes the GUI works and sometimes it doesn't.

joecrop, 2025-09-09:
I was able to recreate this easily by sending a read command from the I2Cdriver gui to a device that is not on the bus. The GUI will lock up and sometimes the I2C driver will keep the clock line held low until I remove it from power.

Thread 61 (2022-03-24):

Windows 11 not playing nice with I2CDriver application

PDE-Paul, 2022-03-24:
Hi,

I recently upgraded to Windows 11 64 bit and now my I2CDriver application (GUI) does not list out COMMPORTS.

My results are exactly the same as this post https://github.com/jamesbowman/i2cdriver/issues/47 except installing the FTDI drivers does not resolve the issue, command line works fine. IO have tried all the suggestions in issue 47 with the same results.

Any advise would be greatly appreciated.

Kind Regards
Paul Brink

jamesbowman, 2022-03-24:
So to confirm: after the upgrade, ``i2ccl`` still works OK, but the I2CGui does not list out the available ports?

PDE-Paul, 2022-03-24:
Yes, That is correct. Using i2ccl, I am able to enable monitoring mode. I have tried i2cgui COM6 and the GUI is displayed with zero items in the COMM dropdown, exactly the same result if I execute the i2cdriver shortcut. I have tried executing as administrator with the same result.

Yet Windows 10 works, I have tried a second laptop earlier.

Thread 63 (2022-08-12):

No register read or write to address id

markiemoosle, 2022-08-12:
In the 'C' source code driver, there isn't the ability to write to register values within a I2C address device Id?

mkohlhaas, 2024-08-06:
And read as well!

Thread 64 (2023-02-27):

Incomplete documentation for MacOS

wolfch, 2023-02-27:
Currently, the `i2cdriver.pdf` claims in the "Overview" section:
> It uses a standard FTDI USB serial chip to talk to the PC, so no special drivers need to be installed.
This may be true for Windows, but not for MacOS, at least for `12.6.3 - "Monterey"`.

When I plugged in the i2cdriver board, I never saw a new character device entry appear matching `/dev/cu.usbserial-*`.  However, after performing a device scan with the "System Information" app, I saw:
```
FT230X Basic UART:

  Product ID:	0x6015
  Vendor ID:	0x0403  (Future Technology Devices International Limited)
  [...more omitted...]
```
So I knew the board was being seen on the USB bus.  Long story short - needed to install an additional driver.  I went to this page:
https://ftdichip.com/drivers/vcp-drivers/
...and chose version `1.5.0` for MacOS 11 or 12 - the direct URL being:
https://ftdichip.com/wp-content/uploads/2022/06/FTDIUSBSerialDextInstaller_1_5_0.dmg

For the latest MacOS releases, rather then installing a `kext` from a `*.pkg` installer, you drag and drop a standard app from the mounted `*.dmg`  to the `/Applications` directory (it _has_ to be run from the `/Applications` directory).  When you start the app and click the "install" button, remember to approve the installation by opening `System Preferences...` then selecting the option to approve pending driver installation.

I did not have to reboot - just unplug and re-plug the i2cdriver board back in the USB - only then did I see the new character mode device, `/dev/tty.usbserial-*` appear and I was able to scan and see attached i2c device addresses.

BTW, forget about being able to use the wxWidget GUI app out-of-the-box on MacOS - you'll get this error message:
> Please run with a Framework build of python, and only when you are logged in on the main display of your Mac

You might be able to get it to work using the https://github.com/pyenv/pyenv version manager to build a whole special Python version from source, as suggested here:
https://stackoverflow.com/questions/48531006/wxpython-this-program-needs-access-to-the-screen

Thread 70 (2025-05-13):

i2cdriver pip package fails to install

zapta, 2025-05-13:
Pip install of ``i2cdriver`` package fails with an error message and exit code. Please see details below.

**ERROR: For req: i2cdriver. Invalid script entry point: <ExportEntry i2cgui = samples.i2cgui:None []> - A callable suffix is required. Cf https://packaging.python.org/specifications/entry-points/#use-for-scripts for more information.**

```
$ python --version
Python 3.13.1

$ pip uninstall i2cdriver
WARNING: Skipping i2cdriver as it is not installed.
/projects$ pip install --no-cache-dir  i2cdriver
Collecting i2cdriver
  Downloading i2cdriver-1.0.5-py3-none-any.whl.metadata (558 bytes)
Requirement already satisfied: pyserial in /Library/Frameworks/Python.framework/Versions/3.13/lib/python3.13/site-packages (from i2cdriver) (3.5)
Downloading i2cdriver-1.0.5-py3-none-any.whl (8.1 kB)
Installing collected packages: i2cdriver
ERROR: For req: i2cdriver. Invalid script entry point: <ExportEntry i2cgui = samples.i2cgui:None []> - A callable suffix is required. Cf https://packaging.python.org/specifications/entry-points/#use-for-scripts for more information.
/projects$ echo $?
1
```

tayken, 2025-05-13:
Just so that everything is together, here is the output from my test:

```
(.venv) tayken@wadew:~/test$ pip install greenpak                                                                                                                                    
Collecting greenpak                                                                   
  Downloading greenpak-0.0.29-py3-none-any.whl.metadata (2.1 kB)    
Collecting hackpyratebus>=0.0.6 (from greenpak)                                       
  Using cached hackPyrateBus-0.0.6-py3-none-any.whl.metadata (4.1 kB)                                                                                                                
Collecting i2c-adapter>=0.0.4 (from greenpak)                                                                                                                                        
  Using cached i2c_adapter-0.2.21-py3-none-any.whl.metadata (3.0 kB)                                                                                                                 
Collecting i2cdriver>=1.0.1 (from greenpak)                                                                                                                                          
  Using cached i2cdriver-1.0.5-py3-none-any.whl.metadata (558 bytes)                                                                                                                 
Collecting intelhex>=2.3.0 (from greenpak)                                            
  Using cached intelhex-2.3.0-py2.py3-none-any.whl.metadata (2.7 kB)
Collecting smbus2==0.4.3 (from greenpak)                                              
  Using cached smbus2-0.4.3-py2.py3-none-any.whl.metadata (7.1 kB)
Collecting pyserial (from hackpyratebus>=0.0.6->greenpak)                                                                                                                            
  Using cached pyserial-3.5-py2.py3-none-any.whl.metadata (1.6 kB)
Downloading greenpak-0.0.29-py3-none-any.whl (23 kB)                                                                                                                                 
Using cached smbus2-0.4.3-py2.py3-none-any.whl (11 kB)                                
Using cached hackPyrateBus-0.0.6-py3-none-any.whl (43 kB)                             
Using cached i2c_adapter-0.2.21-py3-none-any.whl (8.4 kB)                                                                                                                            
Using cached i2cdriver-1.0.5-py3-none-any.whl (8.1 kB)                                
Using cached intelhex-2.3.0-py2.py3-none-any.whl (50 kB)         
Using cached pyserial-3.5-py2.py3-none-any.whl (90 kB)                                
Installing collected packages: smbus2, pyserial, intelhex, i2cdriver, i2c-adapter, hackpyratebus, greenpak
ERROR: For req: i2cdriver>=1.0.1. Invalid script entry point: <ExportEntry i2cgui = samples.i2cgui:None []> - A callable suffix is required. Cf https://packaging.python.org/specifications/en
try-points/#use-for-scripts for more information.                                                                                                                                    
(.venv) tayken@wadew:~/test$ pip install greenpak                                     
Collecting greenpak                                                                   
  Using cached greenpak-0.0.29-py3-none-any.whl.metadata (2.1 kB)                     
Collecting hackpyratebus>=0.0.6 (from greenpak)                                       
  Using cached hackPyrateBus-0.0.6-py3-none-any.whl.metadata (4.1 kB)                 
Collecting i2c-adapter>=0.0.4 (from greenpak)                                         
  Using cached i2c_adapter-0.2.21-py3-none-any.whl.metadata (3.0 kB)                  
Requirement already satisfied: i2cdriver>=1.0.1 in ./.venv/lib/python3.12/site-packages (from greenpak) (1.0.5)
Requirement already satisfied: intelhex>=2.3.0 in ./.venv/lib/python3.12/site-packages (from greenpak) (2.3.0)
Requirement already satisfied: smbus2==0.4.3 in ./.venv/lib/python3.12/site-packages (from greenpak) (0.4.3)
Requirement already satisfied: pyserial in ./.venv/lib/python3.12/site-packages (from hackpyratebus>=0.0.6->greenpak) (3.5)
Using cached greenpak-0.0.29-py3-none-any.whl (23 kB)
Using cached hackPyrateBus-0.0.6-py3-none-any.whl (43 kB)
Using cached i2c_adapter-0.2.21-py3-none-any.whl (8.4 kB)
Installing collected packages: i2c-adapter, hackpyratebus, greenpak
Successfully installed greenpak-0.0.29 hackpyratebus-0.0.6 i2c-adapter-0.2.21
```

My guess is [this line](https://github.com/jamesbowman/i2cdriver/blob/master/python3/pyproject.toml#L21) is the problem. But that's just a guess.

tayken, 2025-05-21:
Actually I think this issue is already resolved in `pyproject.toml` file with https://github.com/jamesbowman/i2cdriver/commit/3e5eeb5a4f0c0b9e943ab6a1a639e17e647776b5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. The only issue is version number stayed the same, so if a new version, aka `1.0.6` is build and pushed, it should solve this issue.

tayken, 2025-05-22:
No need to do anything in `greenpak` as `greenpak` already uses the latest version of `i2cdriver` which is 1.0.5. `i2cdriver` package needs to be bumped up to 1.0.6 and pushed.

zapta, 2025-05-22:
Ok, thanks.

On Wed, May 21, 2025 at 5:39 PM Taylan Ayken ***@***.***>
wrote:

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

jamesbowman, 2025-06-30:
Believe this is fixed in new release 1.0.6

https://pypi.org/project/i2cdriver/1.0.6/

tayken, 2025-07-01:
Yes, the new release solves this issue. I think we close this.

* Installing it by itself:
```
(.venv) tayken@wadew:~$ pip install i2cdriver
Collecting i2cdriver
  Using cached i2cdriver-1.0.6-py3-none-any.whl.metadata (558 bytes)
Collecting pyserial (from i2cdriver)
  Using cached pyserial-3.5-py2.py3-none-any.whl.metadata (1.6 kB)
Using cached i2cdriver-1.0.6-py3-none-any.whl (8.1 kB)
Using cached pyserial-3.5-py2.py3-none-any.whl (90 kB)
Installing collected packages: pyserial, i2cdriver
Successfully installed i2cdriver-1.0.6 pyserial-3.5
```

* Installing it as a dependency:
```
(.venv) tayken@wadew:~$ pip install greenpak
Collecting greenpak
  Using cached greenpak-0.0.30-py3-none-any.whl.metadata (2.1 kB)
Collecting hackpyratebus>=0.0.6 (from greenpak)
  Using cached hackPyrateBus-0.0.6-py3-none-any.whl.metadata (4.1 kB)
Collecting i2c-adapter>=0.0.4 (from greenpak)
  Using cached i2c_adapter-0.2.21-py3-none-any.whl.metadata (3.0 kB)
Collecting i2cdriver>=1.0.1 (from greenpak)
  Downloading i2cdriver-1.0.6-py3-none-any.whl.metadata (558 bytes)
Collecting intelhex>=2.3.0 (from greenpak)
  Using cached intelhex-2.3.0-py2.py3-none-any.whl.metadata (2.7 kB)
Collecting smbus2==0.4.3 (from greenpak)
  Using cached smbus2-0.4.3-py2.py3-none-any.whl.metadata (7.1 kB)
Collecting typing-extensions>=4.7.1 (from greenpak)
  Using cached typing_extensions-4.14.0-py3-none-any.whl.metadata (3.0 kB)
Collecting pyserial (from hackpyratebus>=0.0.6->greenpak)
  Using cached pyserial-3.5-py2.py3-none-any.whl.metadata (1.6 kB)
Using cached greenpak-0.0.30-py3-none-any.whl (23 kB)
Using cached smbus2-0.4.3-py2.py3-none-any.whl (11 kB)
Using cached hackPyrateBus-0.0.6-py3-none-any.whl (43 kB)
Using cached i2c_adapter-0.2.21-py3-none-any.whl (8.4 kB)
Downloading i2cdriver-1.0.6-py3-none-any.whl (8.1 kB)
Using cached intelhex-2.3.0-py2.py3-none-any.whl (50 kB)
Using cached typing_extensions-4.14.0-py3-none-any.whl (43 kB)
Using cached pyserial-3.5-py2.py3-none-any.whl (90 kB)
Installing collected packages: smbus2, pyserial, intelhex, typing-extensions, i2cdriver, i2c-adapter, hackpyratebus, greenpak
Successfully installed greenpak-0.0.30 hackpyratebus-0.0.6 i2c-adapter-0.2.21 i2cdriver-1.0.6 intelhex-2.3.0 pyserial-3.5 smbus2-0.4.3 typing-extensions-4.14.0
```

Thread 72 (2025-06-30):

Register read values of 0x3B and 0x0A print in ASCII

CollinSchairer, 2025-06-30:
Had a confusing afternoon when dumping registers of a device and seeing “;” and “\n” in the console among normal hex codes. Seems these values 0x3B and 0x0A are not being printed/returned as hex code but instead converting to ASCII characters.

Not sure if there’s anything that can be done here as I suspect this is weird behavior from python’s handling of the Bytes object.

jamesbowman, 2025-06-30:
Just checking, is this the kind of thing that you're seeing.

```
>>> bytes([0xf6, 0x0a])
b'\xf6\n'
```

If so, that's Python's unhelpful way of showing a `bytes` object. `bytes` object has a `hex()` method that I use to get a proper dump:

```
>>> x=bytes([0xf6, 0x0a])
>>> x.hex(' ')
'f6 0a'
```

CollinSchairer, 2025-06-30:
Yep, that’s exactly the behavior I saw. Thanks for clarifying, fortunately the display on the I2CDriver was able to show me the proper hex values on the bus.

Closed 2025-06-30.

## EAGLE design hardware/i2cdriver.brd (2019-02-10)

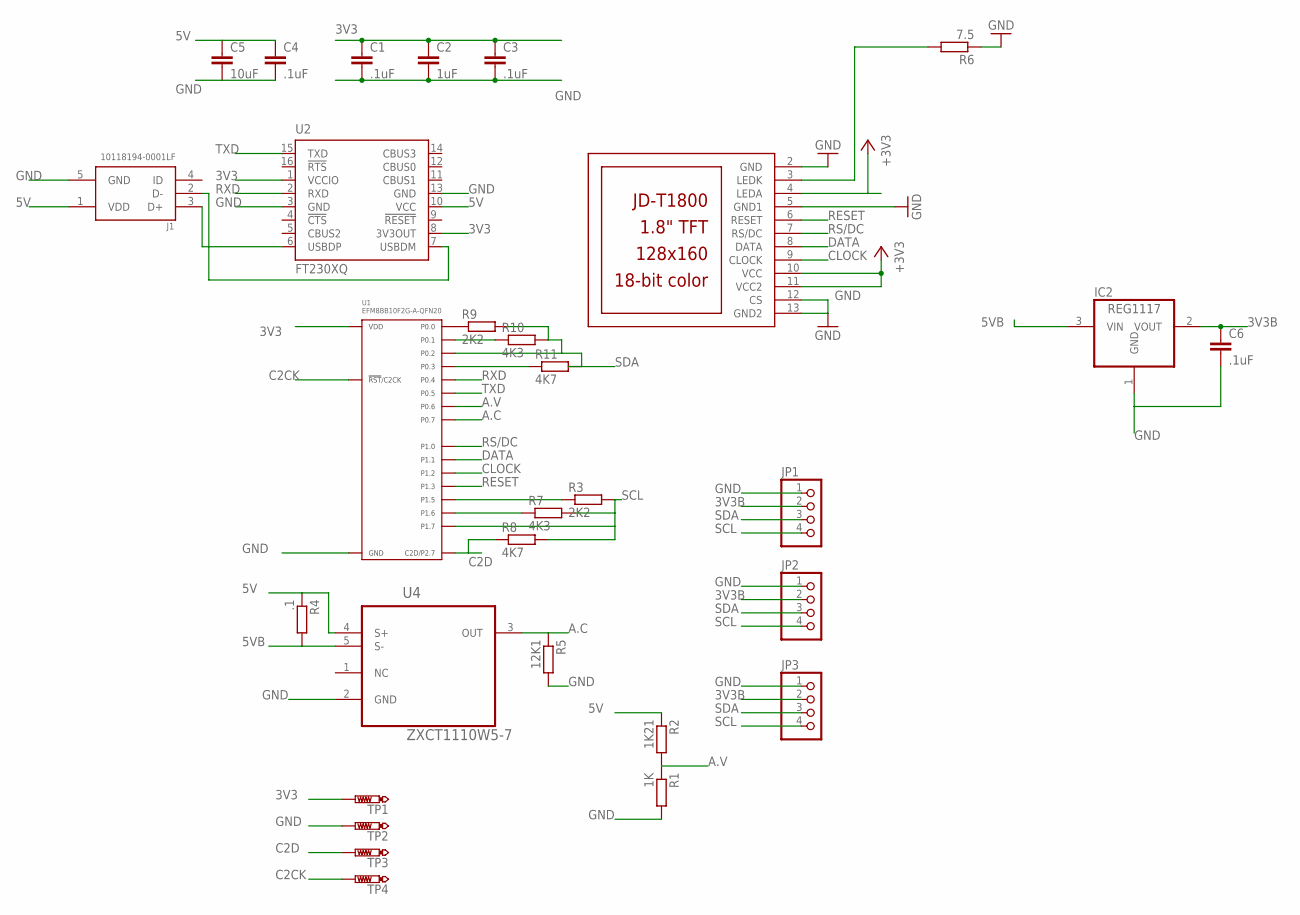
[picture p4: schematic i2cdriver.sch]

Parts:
C1, C3, C4, C6: .1uF; C0402K
C2: 1uF; C0402K
C5: 10uF; C0402K
IC2: REG1117; SOT223
J1: 10118194-0001LF; FRAMATOME_10118194-0001LF
JP1, JP2, JP3: PINHD-1X4/90; 1X04/90
R1: 1K; R0402
R2: 1K21; R0402
R3, R9: 2K2; R0402
R4: .1; R0805
R5: 12K1; R0402
R6: 7.5; R0402
R7, R10: 4K3; R0402
R8, R11: 4K7; R0402
TP1, TP2, TP3, TP4: PTR1B1,27; B1,27
U1: EFM8BB10F2G-A-QFN20; EFM8BB10F(2/4/8)G-A-QFN20; MPN EFM8BB10F2G-A-QFN20
U2: FT230XQ; QFN16
U4: ZXCT1110W5-7; SOT95P280X130-5N
U$1: JD-T1800

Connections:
3V3: C1.1, C2.1, C3.1, TP1.TP, U1.P$4 (VDD), U2.1 (VCCIO), U2.8 (3V3OUT), U$1.4 (LEDA), U$1.10 (VCC), U$1.11 (VCC2)
3V3B: C6.1, IC2.2 (VOUT), JP1.2, JP2.2, JP3.2
5V: C4.1, C5.1, J1.1 (VDD), R2.1, R4.1, U2.10 (VCC), U4.4 (S+)
5VB: IC2.3 (VIN), R4.2, U4.5 (S-)
A.C: R5.1, U1.P$15 (P0.7), U4.3 (OUT)
A.V: R1.1, R2.2, U1.P$16 (P0.6)
C2CK: TP4.TP, U1.P$5 (!RST!/C2CK)
C2D: R8.1, TP3.TP, U1.P$6 (C2D/P2.7)
C2D1: R11.1, U1.P$19 (P0.3)
CLOCK: U1.P$11 (P1.2), U$1.9 (CLOCK)
DATA: U1.P$13 (P1.1), U$1.8 (DATA)
GND: C1.2, C2.2, C3.2, C4.2, C5.2, C6.2, IC2.1 (GND), J1.5 (GND), JP1.1, JP2.1, JP3.1, R1.2, R5.2, R6.1, TP2.TP, U1.P$3 (GND), U1.P$12 (GND), U1.PAD (GND), U2.3 (GND), U2.13 (GND), U4.2 (GND), U$1.2 (GND), U$1.5 (GND1), U$1.12 (CS), U$1.13 (GND2)
unnamed: R10.1, U1.P$1 (P0.1)
unnamed: R7.1, U1.P$7 (P1.6)
unnamed: R3.1, U1.P$8 (P1.5)
unnamed: R6.2, U$1.3 (LEDK)
unnamed: R9.1, U1.P$2 (P0.0)
unnamed: J1.3 (D+), U2.6 (USBDP)
unnamed: J1.2 (D-), U2.7 (USBDM)
RESET: U1.P$10 (P1.3), U$1.6 (RESET)
RS/DC: U1.P$14 (P1.0), U$1.7 (RS/DC)
RXD: U1.P$18 (P0.4), U2.2 (RXD)
SCL: JP1.4, JP2.4, JP3.4, R3.2, R7.2, R8.2, U1.P$9 (P1.7)
SDA: JP1.3, JP2.3, JP3.3, R9.2, R10.2, R11.2, U1.P$20 (P0.2)
TXD: U1.P$17 (P0.5), U2.15 (TXD)

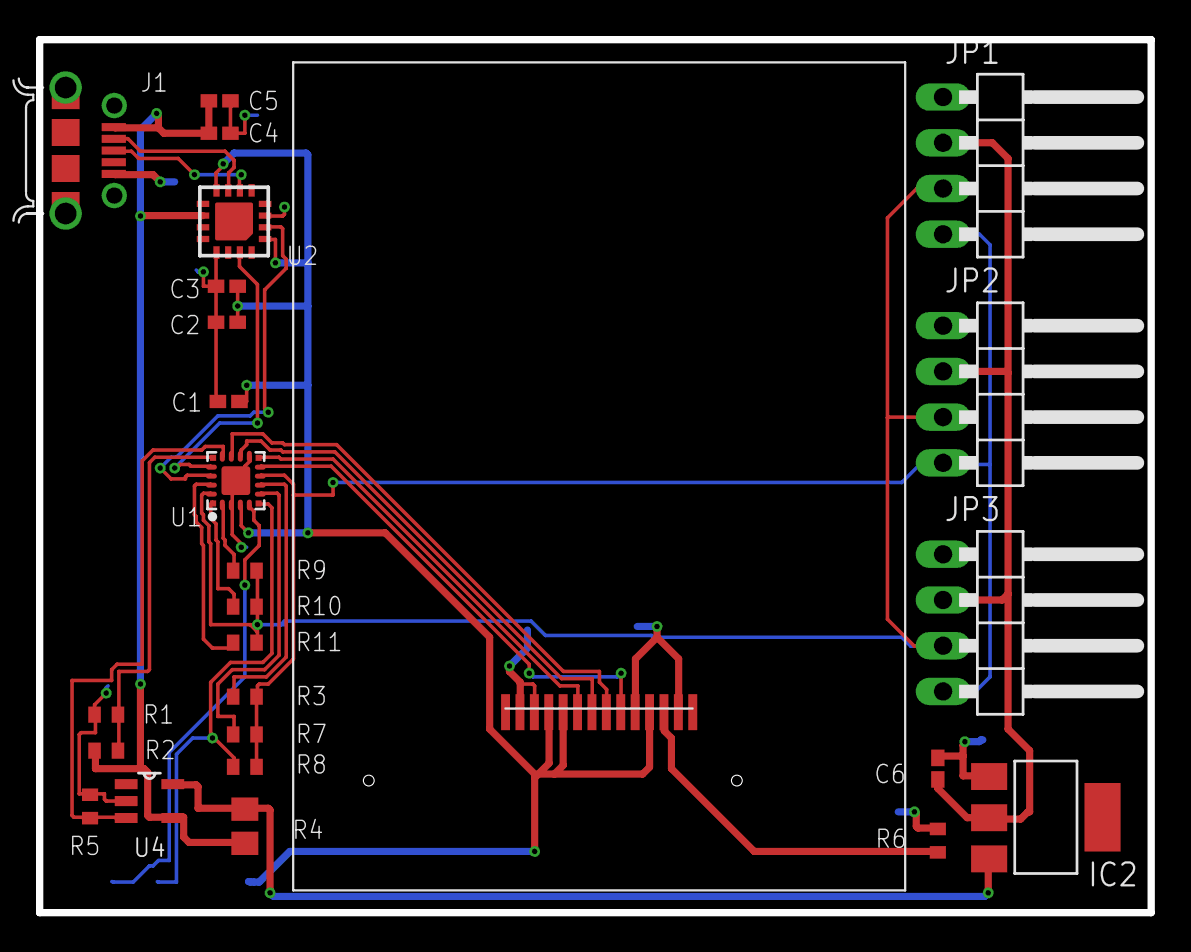
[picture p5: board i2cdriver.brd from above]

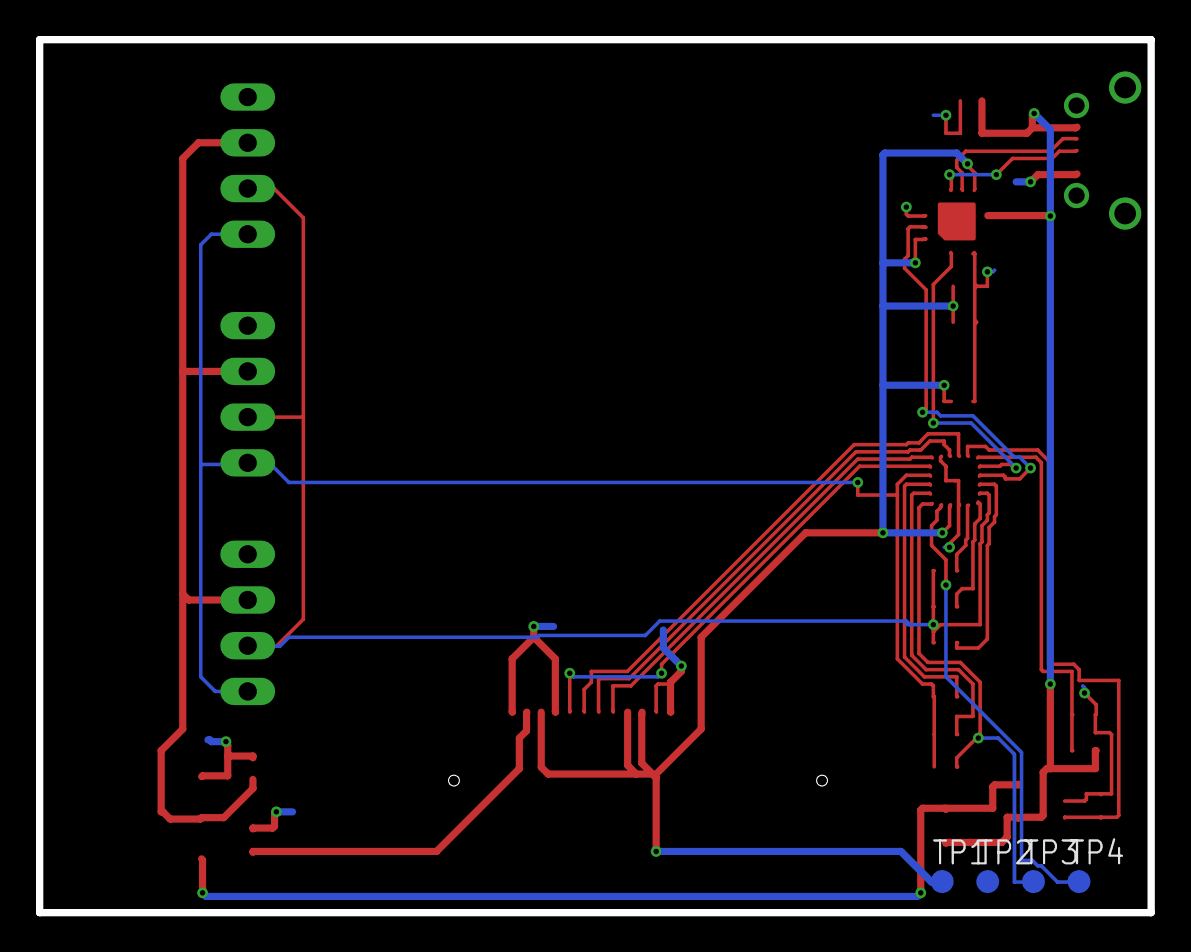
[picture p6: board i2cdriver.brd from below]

Board: 2 copper layers, 61.7 x 48.5 mm, 30 parts (4 on the bottom side), 25 nets.

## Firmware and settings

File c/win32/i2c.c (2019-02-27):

#include <stdio.h>
#include <stdlib.h>

#include "i2cdriver.h"

int main(int argc, char *argv[])
{
  I2CDriver sd;
  if (argc < 2) {
    printf("Usage: i2ccl <PORTNAME> <commands>\n");
    exit(1);
  } else {
    i2c_connect(&sd, argv[1]);
    if (!sd.connected)
      exit(1);
    return i2c_commands(&sd, argc - 2, argv + 2);
  }
}

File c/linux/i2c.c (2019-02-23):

#include <stdio.h>
#include <stdlib.h>

#include "i2cdriver.h"

int main(int argc, char *argv[])
{
  I2CDriver i2c;
  if (argc < 2) {
    printf("Usage: i2ccl <PORTNAME> <commands>\n");
    exit(1);
  } else {
    i2c_connect(&i2c, argv[1]);
    if (!i2c.connected)
      exit(1);
    return i2c_commands(&i2c, argc - 2, argv + 2);
  }
}

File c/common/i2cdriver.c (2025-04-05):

#include <stdio.h>
#include <stdlib.h>
#include <assert.h>
#include <memory.h>
#include <fcntl.h>
#if !defined(WIN32)
#include <sys/ioctl.h>
#include <unistd.h>
#endif
#include <errno.h>
#define __STDC_FORMAT_MACROS
#include <inttypes.h>
#include <string.h>
#include <stdbool.h>

#include "i2cdriver.h"

// ****************************   Serial port  ********************************

#if defined(WIN32)  // {

#ifndef NOMINMAX
#define NOMINMAX
#endif
#include <windows.h>

void ErrorExit(const char *func_name) 
{ 
    // Retrieve the system error message for the last-error code

    LPVOID lpMsgBuf;
    DWORD dw = GetLastError(); 

    FormatMessage(
        FORMAT_MESSAGE_ALLOCATE_BUFFER | 
        FORMAT_MESSAGE_FROM_SYSTEM |
        FORMAT_MESSAGE_IGNORE_INSERTS,
        NULL,
        dw,
        MAKELANGID(LANG_NEUTRAL, SUBLANG_DEFAULT),
        (LPTSTR) &lpMsgBuf,
        0, NULL );

    // Display the error message and exit the process

    char mm[256];
    snprintf(mm, sizeof(mm), "%s failed with error %lu:\n%s", func_name, dw, (char*)lpMsgBuf); 
    MessageBox(NULL, (LPCTSTR)mm, TEXT("Error"), MB_OK); 

    LocalFree(lpMsgBuf);
    ExitProcess(dw); 
}

HANDLE openSerialPort(const char *portname)
{
    char fullname[10];
    const char *fmt;
    if (portname[0] == 'C')
        fmt = "\\\\.\\%s";
    else
        fmt = "%s";
    snprintf(fullname, sizeof(fullname), fmt, portname);
    DWORD  accessdirection = GENERIC_READ | GENERIC_WRITE;
    HANDLE hSerial = CreateFile((LPCSTR)fullname,
        accessdirection,
        0,
        0,
        OPEN_EXISTING,
        0,
        0);
    if (hSerial == INVALID_HANDLE_VALUE) {
        ErrorExit("CreateFile");
    }
    DCB dcbSerialParams = {0};
    dcbSerialParams.DCBlength=sizeof(dcbSerialParams);
    if (!GetCommState(hSerial, &dcbSerialParams)) {
         ErrorExit("GetCommState");
    }
    dcbSerialParams.BaudRate = 1000000;
    dcbSerialParams.ByteSize = 8;
    dcbSerialParams.StopBits = ONESTOPBIT;
    dcbSerialParams.Parity = NOPARITY;
    if (!SetCommState(hSerial, &dcbSerialParams)) {
         ErrorExit("SetCommState");
    }
    COMMTIMEOUTS timeouts = {0};
    timeouts.ReadIntervalTimeout = 50;
    timeouts.ReadTotalTimeoutConstant = 50;
    timeouts.ReadTotalTimeoutMultiplier = 10;
    timeouts.WriteTotalTimeoutConstant = 50;
    timeouts.WriteTotalTimeoutMultiplier = 10;
    if (!SetCommTimeouts(hSerial, &timeouts)) {
        ErrorExit("SetCommTimeouts");
    }
    return hSerial;
}

DWORD readFromSerialPort(HANDLE hSerial, uint8_t * buffer, int buffersize)
{
    DWORD dwBytesRead = 0;
    if (!ReadFile(hSerial, buffer, buffersize, &dwBytesRead, NULL)) {
        ErrorExit("ReadFile");
    }
    return dwBytesRead;
}

DWORD writeToSerialPort(HANDLE hSerial, const uint8_t * data, int length)
{
    DWORD dwBytesRead = 0;
    if (!WriteFile(hSerial, data, length, &dwBytesRead, NULL)) {
        ErrorExit("WriteFile");
    }
    return dwBytesRead;
}

void closeSerialPort(HANDLE hSerial)
{
    CloseHandle(hSerial);
}

#else               // }{

#include <termios.h>

int openSerialPort(const char *portname)
{
  struct termios Settings;
  int fd;
  
  fd = open(portname, O_RDWR | O_NOCTTY);
  if (fd == -1) {
    perror(portname);
    return -1;
  }
  tcgetattr(fd, &Settings);

#if defined(__APPLE__) && !defined(B1000000)
  #include <IOKit/serial/ioss.h>
#else
  cfsetispeed(&Settings, B1000000);
  cfsetospeed(&Settings, B1000000);
#endif


  cfmakeraw(&Settings);
  Settings.c_cc[VMIN] = 1;
  if (tcsetattr(fd, TCSANOW, &Settings) != 0) {
    perror("Serial settings");
    return -1;
  }

#if defined(__APPLE__) && !defined(B1000000)
  speed_t speed = (speed_t)1000000;
  ioctl(fd, IOSSIOSPEED, &speed);
#endif

  return fd;
}

int readFromSerialPort(int fd, uint8_t *b, size_t s)
{
  ssize_t n, t;
  t = 0;
  while (t < s) {
    n = read(fd, b + t, s);
    if (n > 0)
      t += n;
  }
#ifdef VERBOSE
  printf(" READ %d %d: ", (int)s, (int)n);
  int i;
  for (i = 0; i < s; i++)
    printf("%02x ", 0xff & b[i]);
  printf("\n");
#endif
  return s;
}

void writeToSerialPort(int fd, const uint8_t *b, size_t s)
{
  write(fd, b, s);
#ifdef VERBOSE
  printf("WRITE %u: ", (int)s);
  int i;
  for (i = 0; i < s; i++)
    printf("%02x ", 0xff & b[i]);
  printf("\n");
#endif  
}

void closeSerialPort(HANDLE hSerial)
{
    close((int)hSerial);
}

#endif              // }

// ******************************  CCITT CRC  *********************************

static const uint16_t crc_table[256] = {
    0x0000, 0x1021, 0x2042, 0x3063, 0x4084, 0x50a5, 0x60c6, 0x70e7,
    0x8108, 0x9129, 0xa14a, 0xb16b, 0xc18c, 0xd1ad, 0xe1ce, 0xf1ef,
    0x1231, 0x0210, 0x3273, 0x2252, 0x52b5, 0x4294, 0x72f7, 0x62d6,
    0x9339, 0x8318, 0xb37b, 0xa35a, 0xd3bd, 0xc39c, 0xf3ff, 0xe3de,
    0x2462, 0x3443, 0x0420, 0x1401, 0x64e6, 0x74c7, 0x44a4, 0x5485,
    0xa56a, 0xb54b, 0x8528, 0x9509, 0xe5ee, 0xf5cf, 0xc5ac, 0xd58d,
    0x3653, 0x2672, 0x1611, 0x0630, 0x76d7, 0x66f6, 0x5695, 0x46b4,
    0xb75b, 0xa77a, 0x9719, 0x8738, 0xf7df, 0xe7fe, 0xd79d, 0xc7bc,
    0x48c4, 0x58e5, 0x6886, 0x78a7, 0x0840, 0x1861, 0x2802, 0x3823,
    0xc9cc, 0xd9ed, 0xe98e, 0xf9af, 0x8948, 0x9969, 0xa90a, 0xb92b,
    0x5af5, 0x4ad4, 0x7ab7, 0x6a96, 0x1a71, 0x0a50, 0x3a33, 0x2a12,
    0xdbfd, 0xcbdc, 0xfbbf, 0xeb9e, 0x9b79, 0x8b58, 0xbb3b, 0xab1a,
    0x6ca6, 0x7c87, 0x4ce4, 0x5cc5, 0x2c22, 0x3c03, 0x0c60, 0x1c41,
    0xedae, 0xfd8f, 0xcdec, 0xddcd, 0xad2a, 0xbd0b, 0x8d68, 0x9d49,
    0x7e97, 0x6eb6, 0x5ed5, 0x4ef4, 0x3e13, 0x2e32, 0x1e51, 0x0e70,
    0xff9f, 0xefbe, 0xdfdd, 0xcffc, 0xbf1b, 0xaf3a, 0x9f59, 0x8f78,
    0x9188, 0x81a9, 0xb1ca, 0xa1eb, 0xd10c, 0xc12d, 0xf14e, 0xe16f,
    0x1080, 0x00a1, 0x30c2, 0x20e3, 0x5004, 0x4025, 0x7046, 0x6067,
    0x83b9, 0x9398, 0xa3fb, 0xb3da, 0xc33d, 0xd31c, 0xe37f, 0xf35e,
    0x02b1, 0x1290, 0x22f3, 0x32d2, 0x4235, 0x5214, 0x6277, 0x7256,
    0xb5ea, 0xa5cb, 0x95a8, 0x8589, 0xf56e, 0xe54f, 0xd52c, 0xc50d,
    0x34e2, 0x24c3, 0x14a0, 0x0481, 0x7466, 0x6447, 0x5424, 0x4405,
    0xa7db, 0xb7fa, 0x8799, 0x97b8, 0xe75f, 0xf77e, 0xc71d, 0xd73c,
    0x26d3, 0x36f2, 0x0691, 0x16b0, 0x6657, 0x7676, 0x4615, 0x5634,
    0xd94c, 0xc96d, 0xf90e, 0xe92f, 0x99c8, 0x89e9, 0xb98a, 0xa9ab,
    0x5844, 0x4865, 0x7806, 0x6827, 0x18c0, 0x08e1, 0x3882, 0x28a3,
    0xcb7d, 0xdb5c, 0xeb3f, 0xfb1e, 0x8bf9, 0x9bd8, 0xabbb, 0xbb9a,
    0x4a75, 0x5a54, 0x6a37, 0x7a16, 0x0af1, 0x1ad0, 0x2ab3, 0x3a92,
    0xfd2e, 0xed0f, 0xdd6c, 0xcd4d, 0xbdaa, 0xad8b, 0x9de8, 0x8dc9,
    0x7c26, 0x6c07, 0x5c64, 0x4c45, 0x3ca2, 0x2c83, 0x1ce0, 0x0cc1,
    0xef1f, 0xff3e, 0xcf5d, 0xdf7c, 0xaf9b, 0xbfba, 0x8fd9, 0x9ff8,
    0x6e17, 0x7e36, 0x4e55, 0x5e74, 0x2e93, 0x3eb2, 0x0ed1, 0x1ef0
};
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

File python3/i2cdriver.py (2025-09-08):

import sys
import serial
import time
import struct
from collections import OrderedDict

__version__ = '1.0.6'

PYTHON2 = (sys.version_info < (3, 0))

import EDS

class I2CTimeout(Exception):
    pass

class InternalState(OrderedDict):
    def __repr__(self):
        return "".join(["%8s %4x\n" % (k, v) for (k, v) in self.items()])

class _I2CEvent:
    def rrw(self):
        return ["WRITE", "READ"][self.rw]
    def rack(self):
        return ["NACK", "ACK"][self.ack]

class START(_I2CEvent):
    def __init__(self, addr, rw, ack):
        self.addr = addr
        self.rw = rw
        self.ack = ack
    def __repr__(self):
        return "<START 0x%02x %s %s>" % (self.addr, self.rrw(), self.rack())
    def dump(self, f, fmt):
        if fmt == "csv":
            f.writerow(("START", self.rrw(), str(self.addr), self.rack()))
        else:
            assert False, "unsupported format"
    def __eq__(self, other):
        return (self.addr, self.rw, self.ack) == (other.addr, other.rw, other.ack)

class STOP(_I2CEvent):
    def __repr__(self):
        return "<STOP>"
    def dump(self, f, fmt):
        if fmt == "csv":
            f.writerow(("STOP", None, None, None))
        else:
            assert False, "unsupported format"
    def __eq__(self, other):
        return isinstance(other, STOP)

class BYTE(_I2CEvent):
    def __init__(self, b, rw, ack):
        self.b = b
        self.rw = rw
        self.ack = ack
    def __repr__(self):
        return "<%s 0x%02x %s>" % (self.rrw(), self.b, self.rack())
    def dump(self, f, fmt):
        if fmt == "csv":
            f.writerow(("BYTE", self.rrw(), str(self.b), self.rack()))
        else:
            assert False, "unsupported format"
    def __eq__(self, other):
        return (self.b, self.rw, self.ack) == (other.b, other.rw, other.ack)

class I2CDriver:
    """
    A connected I2CDriver.

    :param port: The USB port to connect to
    :type port: str
    :param reset: Issue an I2C bus reset on connection
    :type reset: bool

    After connection, the following object variables reflect the current values of the I2CDriver.
    They are updated by calling :py:meth:`getstatus`.

    :ivar product: product code e.g. 'i2cdriver1' or 'i2cdriverm'
    :ivar serial: serial string of I2CDriver
    :ivar uptime: time since I2CDriver boot, in seconds
    :ivar voltage: USB voltage, in V
    :ivar current: current used by attached device, in mA
    :ivar temp: temperature, in degrees C
    :ivar scl: state of SCL
    :ivar sda: state of SDA
    :ivar speed: current device speed in KHz (100 or 400)
    :ivar mode: IO mode (I2C or bitbang)
    :ivar pullups: programmable pullup enable pins
    :ivar ccitt_crc: CCITT-16 CRC of all transmitted and received bytes

    """
    def __init__(self, port = "/dev/ttyUSB0", reset = True):
        """
        Connect to a hardware i2cdriver.

        :param port: The USB port to connect to
        :type port: str
        :param reset: Issue an I2C bus reset on connection
        :type reset: bool

        """
        self.ser = serial.Serial(port, 1000000, timeout = 1)

        # May be in capture or monitor mode, send char and wait for 50 ms
        self.ser.write(b'@')
        time.sleep(.050)

        # May be waiting up to 64 bytes of input (command code 0xff)
        self.ser.write(b'@' * 64)
        self.ser.flush()

        while self.ser.inWaiting():
            self.ser.read(self.ser.inWaiting())

        for c in [0x55, 0x00, 0xff, 0xaa]:
            r = self.__echo(c)
            if r != c:
                print('Echo test failed - not attached?')
                print('Expected %r but received %r' % (c, r))
                raise IOError
        self.getstatus()
        if reset == "never":
            return
        if reset or (self.scl, self.sda) != (1, 1):
            if self.reset() != 3:
                raise I2CTimeout("Bus failed to reset - check connected devices")
            self.getstatus()
        self.setspeed(100)

    if PYTHON2:
        def __ser_w(self, s):
            if isinstance(s, list) or isinstance(s, tuple):
                s = "".join([chr(c) for c in s])
            self.ser.write(s)
    else:
        def __ser_w(self, s):
            if isinstance(s, list) or isinstance(s, tuple):
                s = bytes(s)
            self.ser.write(s)

    def __echo(self, c):
        self.__ser_w([ord('e'), c])
        r = self.ser.read(1)
        if PYTHON2:
            return ord(r[0])
        else:
            return r[0]

    def setspeed(self, s):
        """
        Set the I2C bus speed.

        :param s: speed in KHz, either 100 or 400
        :type s: int
        """
        assert s in (100, 400)
        c = {100:b'1', 400:b'4'}[s]
        self.__ser_w(c)
        self.speed = s

    def setpullups(self, s):
        """
        Set the I2CDriver pullup resistors

        :param s: 6-bit pullup mask
        """
        assert 0 <= s < 64
        self.__ser_w([ord('u'), s])
        self.pullups = s

    def scan(self, silent = False):
        """ Performs an I2C bus scan.
        If silent is False, prints a map of devices.
        Returns a list of the device addresses.

        >>> i2c.scan()
        -- -- -- -- -- -- -- -- 
        -- -- -- -- -- -- -- -- 
        -- -- -- -- 1C -- -- -- 
        -- -- -- -- -- -- -- -- 
        -- -- -- -- -- -- -- -- 
        -- -- -- -- -- -- -- -- 
        -- -- -- -- -- -- -- -- 
        -- -- -- -- -- -- -- -- 
        48 -- -- -- -- -- -- -- 
        -- -- -- -- -- -- -- -- 
        -- -- -- -- -- -- -- -- 
        -- -- -- -- -- -- -- -- 
        68 -- -- -- -- -- -- -- 
        -- -- -- -- -- -- -- -- 
        [28, 72, 104]
        """

        self.ser.write(b'd')
        d = struct.unpack("112c", self.ser.read(112))
        if not silent:
            for a,p in enumerate(d, 8):
                if p == b"1":
                    st = "%02X" % a
                else:
                    st = "--"
                sys.stdout.write(st + " ")
                if (a % 8) == 7:
                    sys.stdout.write("\n")
        return [a for a,p in enumerate(d, 8) if p == b"1"]

    def reset(self):
        """ Send an I2C bus reset """
        self.__ser_w(b'x')
        return struct.unpack("B", self.ser.read(1))[0] & 3

    def start(self, dev, rw):
        """
        Start an I2C transaction

        :param dev: 7-bit I2C device address
        :param rw: read (1) or write (0)

        To write bytes ``[0x12,0x34]`` to device ``0x75``:

        >>> i2c.start(0x75, 0)
        >>> i2c.write([0x12,034])
        >>> i2c.stop()

        """
        self.__ser_w([ord('s'), (dev << 1) | rw])
        return self.ack()

    def ack(self):
        a = ord(self.ser.read(1))
        if a & 2:
            raise I2CTimeout
        return (a & 1) != 0
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

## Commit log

2019-02-10 import PCB design
    [i2cdriver.brd, i2cdriver.sch]
2019-02-20 First sample
2019-02-21 Sample for EDS LED part
2019-02-21 DIG2, BEEP, EPROM samples
2019-02-21 clock sample
2019-02-21 EDS CLOCK class and sample, using datetime
2019-02-23 C API first cut, i2ccl running
2019-02-23 Monitor mode in C API and i2ccl
2019-02-24 Test case builds i2ccl
2019-02-24 Add EDS-IR sample, EDS-take-a-ticket sample
2019-02-24 sample for the POT, and an egg-timer app
2019-02-24 Add proper comment to egg timer
2019-02-24 Consistent case for CLOCK
2019-02-24 Add COMPASS code and sample, color compass app
2019-02-25 ACCEL class and sample
2019-02-25 i2cgui now has heat map and monitor mode button
2019-02-25 Fix custom baud rate for termios on apple
    [i2cdriver.c]
2019-02-27 win32 Makefile for i2ccl.exe
2019-03-01 Fixed GridFlex error Fixed reg-ex for os x serial port selection
    [i2cgui.py]
2019-03-02 Raduio buttons for i2c device
2019-03-02 Add write/read/stop buttons
2019-03-02 I2C reset button
2019-03-03 regwr accepts tuples properly. Fix EDS.LED for Python 2
    [EDS.py, i2cdriver.py]
2019-03-04 LED 8x8 example
2019-03-04 BNO080 IMU sample
2019-03-04 Sparkfun MAG3110 3D Magnetometer
2019-03-10 Update README.md
    Be more explicit about running i2cgui #9
2019-03-17 TEMP sample
2019-03-18 i2cgui now accepts a port on the command-line [#9]
2019-03-22 Better handling of device fails
    [i2cgui.py]
2019-03-23 Fix device range to be 08-77
    [i2cgui.py]
2019-03-29 Clean up handling of selected device when it appears/disappears from network #12
2019-04-03 First cut of pullup control [#7]
2019-04-26 i2cgui installed as a script, version bump to 0.0.5
2019-05-11 added function to set i2c start bit to public API
2019-09-10 Instantiate GridSizer() in a way that works on both Wx 3. and 4.
    Looks like GridSizer.SetHGap() and SetVGap() have no effect on Wx 3.
    But at least now it doesn't crash on Wx 3.
    [i2cgui.py]
2019-09-10 Fix EDS DIG2 raw method
    [EDS.py]
2020-01-07 Acceptance test for i2cdriver and i2cmini firmware
2020-01-08 Correctly hangle regrd with count of 256 or greater.
    [#28]
    [i2cdriver.py]
2020-01-16 Sphinx doc first cut
2020-01-21 Add 'x' command (bus reset) to C common header and i2ccl.
    [#30]
    [i2cdriver.c]
2020-02-19 Add example using a TCA9548A I2C switch
2020-03-06 Fix cast for clang/clang++ in -c++17 mode, using a C-style cast so it's buildable by plain C users.
    Add Makefile.clang
    Add regression test for Travis
    [#39]
    [i2cdriver.c]
2020-03-06 Add capture mode support to API and i2ccl
2020-03-06 Don't do a device scan when bus is blocked. Properly handle capture file cancel path.
2020-03-16 PCA9685 sample
2022-02-05 BM390 sample, by Adafruit
2024-05-22 Added i2c_disconnect to c sdk
    * Added closeSerialPort() for Linux build
    * i2c_disconnect() closes the serial port, and resets the `connected` flag to zero.
    [i2cdriver.c]
2024-06-05 feat(i2c): add baud rate setting functionality
    Add a new function `i2c_setbaud` allowing the baud rate of the I2C connection to be set. This feature provides the ability to configure the communication speed to standard values (100kbps or 400kbps)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
2025-03-12 refactor(i2cgui): use daemon parameter in Thread initialization
    Simplified the creation of the threading.Thread by utilizing the 'daemon' keyword argument directly during instantiation. This enhances code readability and aligns with modern Python practices. The f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
2025-04-05 Rewrite i2c_setbaud() as i2c_setspeed()
2025-04-07 Samples included
2025-09-08 Fix broken EDS LED, using old regwr() method
    [EDS.py, i2cdriver.py]
2025-09-08 Fix EDS LED
